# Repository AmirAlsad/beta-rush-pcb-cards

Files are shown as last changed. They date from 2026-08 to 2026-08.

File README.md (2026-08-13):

# Rush Cards — MIT Beta Theta Pi

<p align="center">
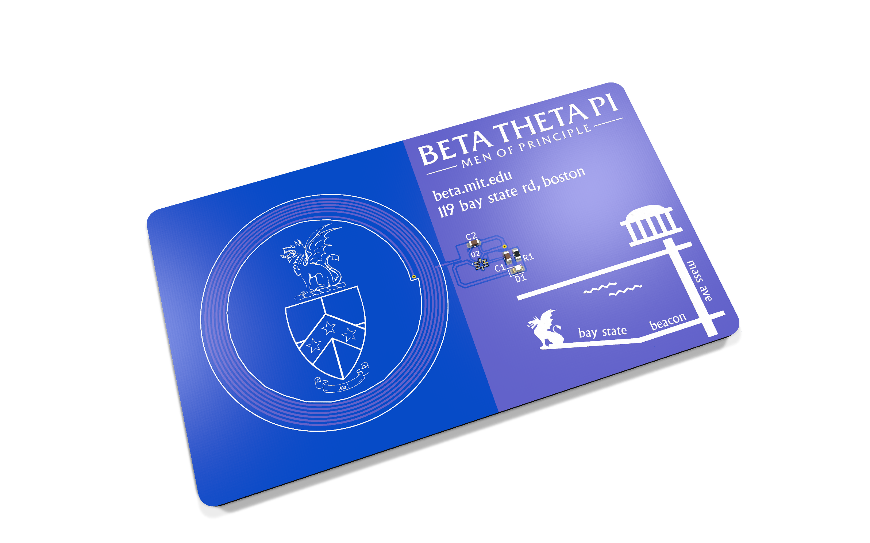
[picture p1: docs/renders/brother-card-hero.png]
The brother card
  
</p>

Two PCB cards designed for **Beta Theta Pi, Beta Eta chapter (MIT)** rush week,
**August 30 – September 6, 2025**. They are circuit boards, not cardstock — the
whole point was that handing someone a PCB is memorable in a way a paper flyer
never is.

**400 cards were made** by JLCPCB — 50 assembled NFC cards and 350 schedule cards — for
**about $400 all-in**. Everything needed to order more is in this repo, including the
exact files JLCPCB received.

> Budget note: the PCB line items were only **$109.80** of that $400. Assembly,
> components, shipping, and import tariffs made up the rest, with freight and tariffs
> taking a large share. **The order-page price is roughly a quarter of what you actually
> pay.** See [`docs/order-history.md`](./docs/order-history.md).

| | |
|---|---|
| **Brother card** | A working NFC tag. A brother taps it to a phone and the phone opens the chapter's rush link. Carried by brothers during rush. **Blue, 1 mm, 50 made, assembled by JLCPCB.** |
| **PNM card** | A silkscreen-only board printing the full week's event schedule, the house address, and the van-pickup number. Handed to PNMs (prospective new members). **Green, 1 mm, 350 made.** |

Designed in **KiCad 9.0.2**. Both boards were fabricated and used.

> **Note for anyone reordering: both cards are 1 mm thick, and every KiCad file here
> says 1.6 mm.** Thickness is an order-page setting that isn't carried in the gerbers,
> so nothing will warn you. Same for the mask colours, which KiCad doesn't store at all.
> [`docs/order-history.md`](./docs/order-history.md) has the complete as-ordered spec.

---

## The boards

### Brother card — front and back

<p align="center">
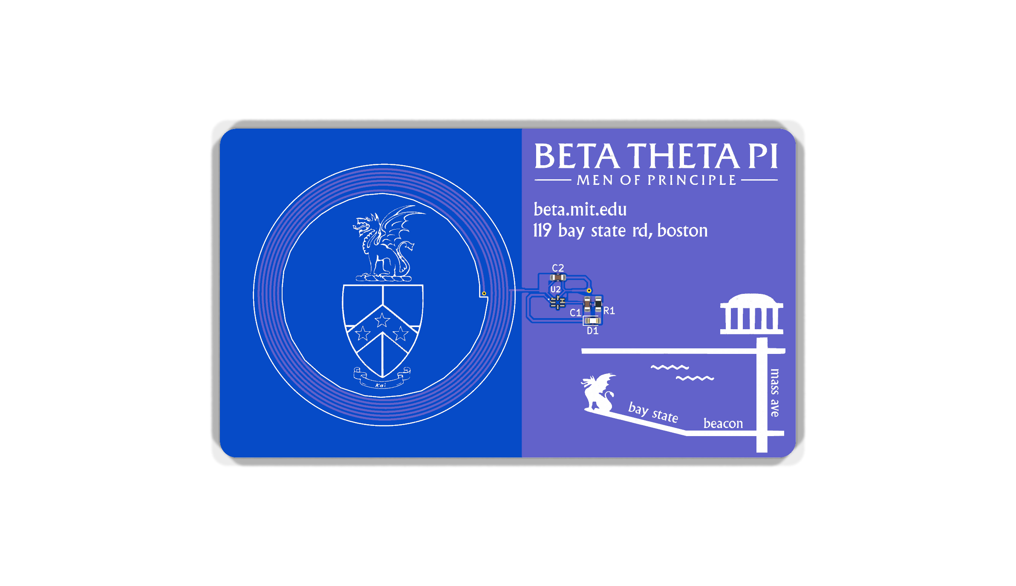
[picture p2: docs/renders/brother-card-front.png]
Brother card front
  
</p>

The left half is a 6-turn spiral NFC antenna in copper, with the Beta crest and
dragon sitting inside the coil. The right half carries the wordmark, the house
address, the tiny NFC circuit (`U2`, `C1`, `C2`, `R1`, `D1`), and a stylized map
of the walk from campus to 119 Bay State Rd — MIT's dome, Mass Ave, the Charles,
Bay State, Beacon.

<p align="center">
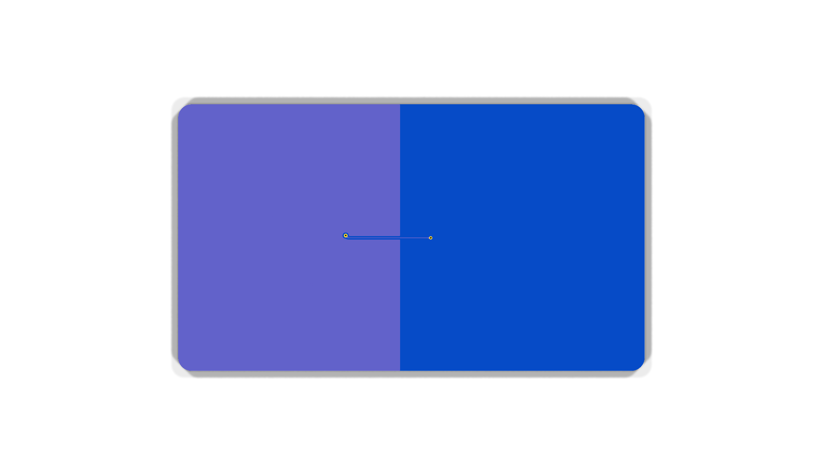
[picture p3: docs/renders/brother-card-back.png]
Brother card back
  
</p>

The back is nearly empty by design: two pads and one short trace that carry the
inner end of the coil back out from under itself. **The two-tone split is not two
solder-mask colours** — it is bare copper zones used as artwork, so a single blue mask
reads as two shades. Never order "two-colour mask" for these.

### PNM card — front and back

<p align="center">
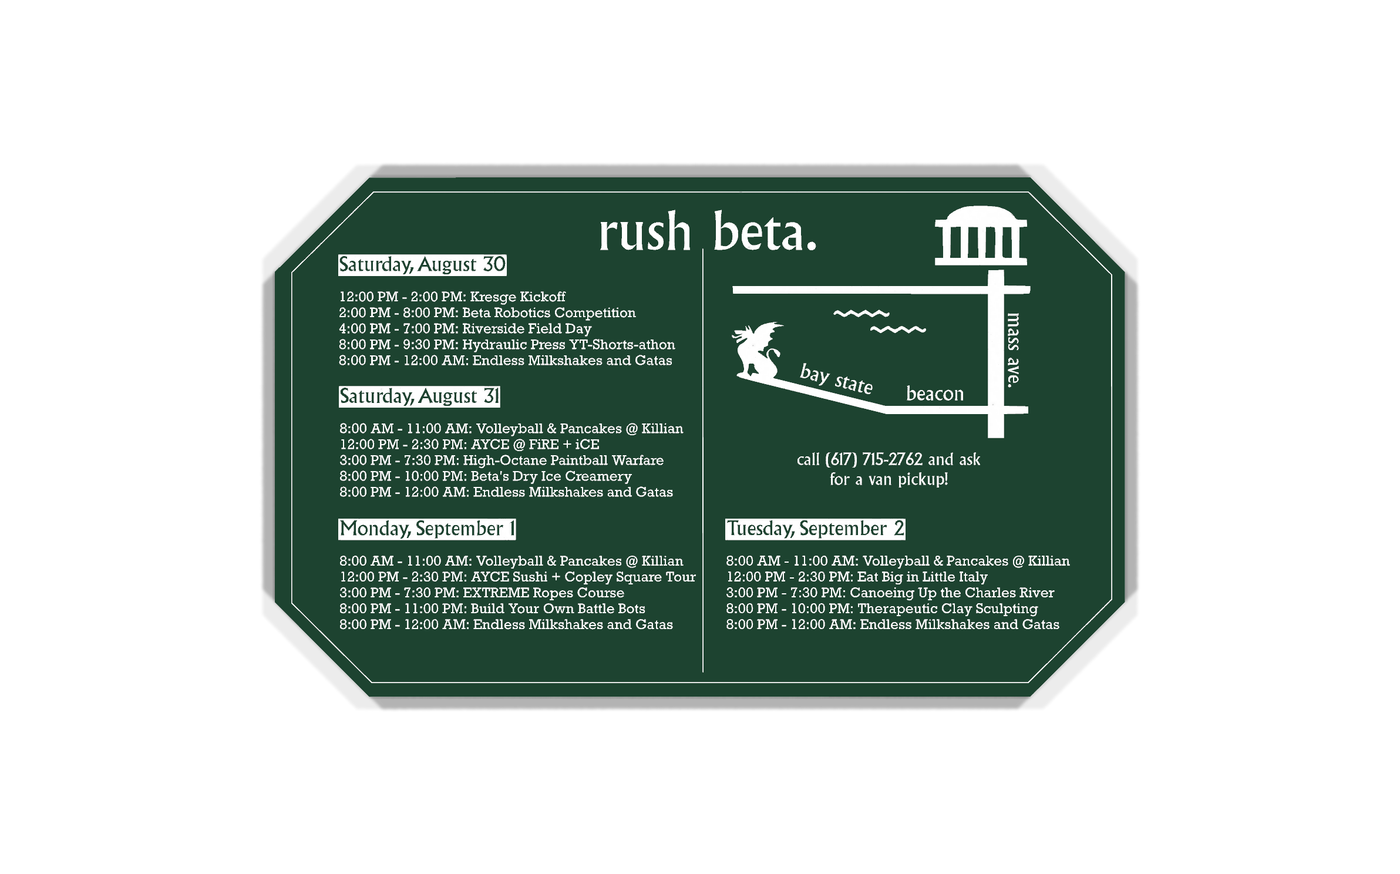
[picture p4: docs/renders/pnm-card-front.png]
PNM card front
  
</p>
<p align="center">
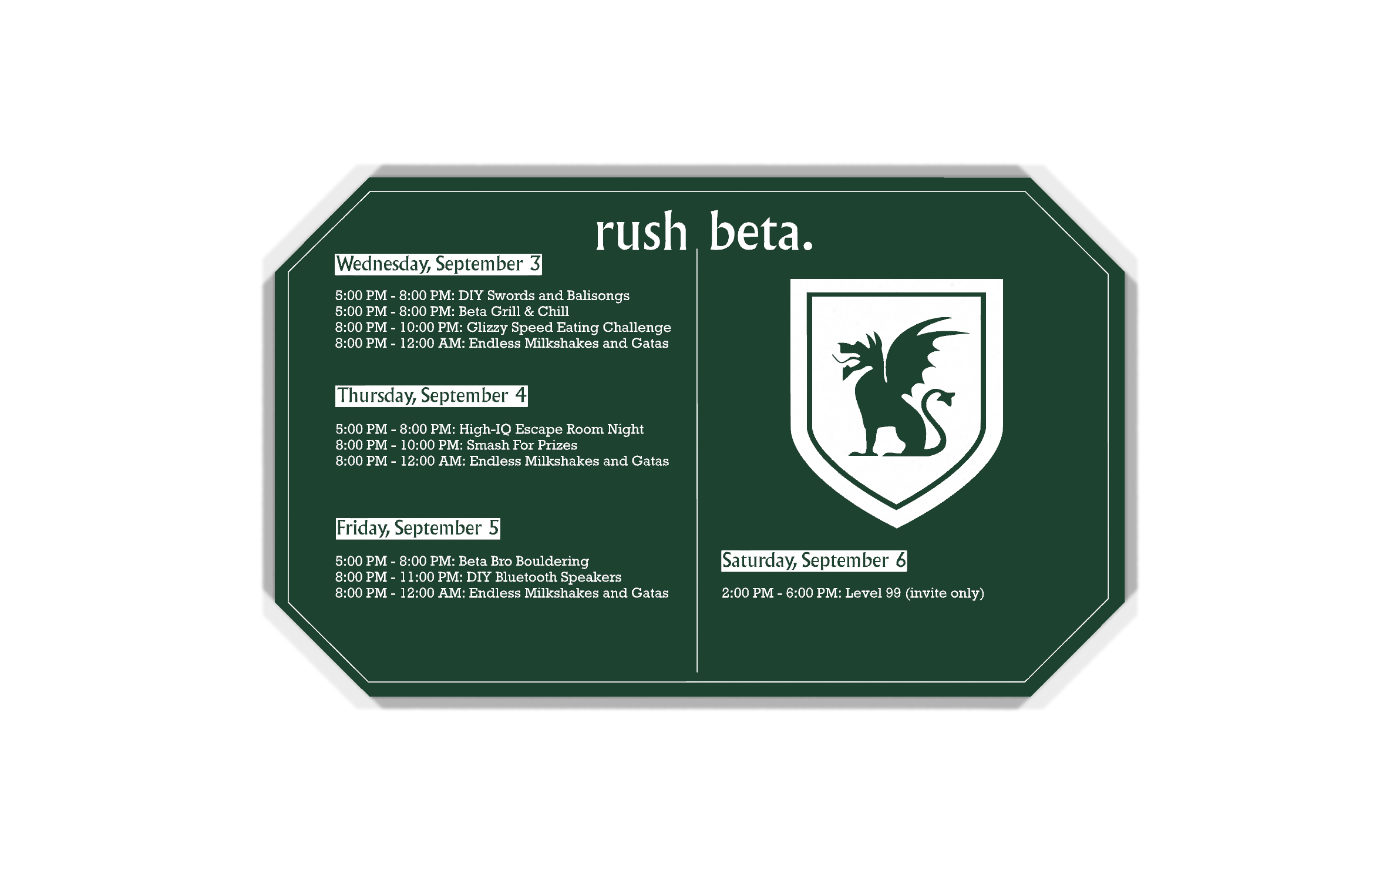
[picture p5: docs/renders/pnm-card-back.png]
PNM card back
  
</p>

Silkscreen only — no components, no nets, nothing to solder. Note the
**octagonal outline**: the corners are clipped on `Edge.Cuts`, which means the
fab has to rout the profile rather than just shear a rectangle.

---

## Repo map

```
.
├── brother-card/        ← the NFC card that was fabricated (v2, 2025-07-30)
├── brother-card-v1/     ← earlier iteration, NEVER fabricated (2025-07-06)
├── pnm-card/            ← the schedule card that was fabricated (2025-07-30)
├── lib/                 ← btp.pretty + btp.kicad_sym  (MUST stay next to the projects)
├── tools/
│   └── render-boards.sh ← regenerates docs/renders/ in the as-ordered mask colours
└── docs/
    ├── order-history.md       ← the 2025 JLCPCB order: spec, prices, parts, gotchas
    ├── reordering.md          ← how to get more cards made
    ├── next-year-checklist.md ← what to change to reuse these for a new rush
    ├── programming-the-tag.md ← how to write the rush link onto a card
    ├── kicad-setup.md         ← opening these files years from now
    ├── nfc-theory.md          ← upstream's full antenna derivation, credited
    ├── OPEN-QUESTIONS.md      ← what still isn't recorded anywhere
    ├── order-history/         ← JLCPCB order screenshots + production records
    ├── renders/               ← generated board renders (+ upstream's Blender model)
    ├── images/                ← upstream's figures, referenced by nfc-theory.md
    ├── antenna-simulations/   ← upstream's LTSpice + MATLAB work
    └── reference/             ← NXP AN11276, ST AN2972, antenna calculators
```

Each card directory holds its own `README.md` with the real detail, the KiCad
source, and a `fab/` folder containing the exact gerbers that were sent out —
**verified byte-identical to the files JLCPCB received.**

**Want to just order more cards?** You don't need KiCad at all. Go straight to
[`docs/reordering.md`](./docs/reordering.md), upload the `fab/…_release/` folders, and
set 1 mm thickness with the right mask colour.

## Opening these in KiCad

```sh
git clone <this repo>
cd RushCards
open brother-card/PCB_Business_Card.kicad_pro   # macOS; or File ▸ Open Project
```

Two things to know before you do, both covered in
[`docs/kicad-setup.md`](./docs/kicad-setup.md):

1. **Don't move `lib/`.** Each project's `fp-lib-table` resolves the artwork
   library as `${KIPRJMOD}/../lib/btp.pretty`. That relative hop is the only
   reason the boards open with their footprints intact — the original design
   depended on a library registered *globally* on one laptop, which would have
   made this repo useless to anyone else. Vendoring it was the single most
   important fix made when archiving.
2. These were built in **KiCad 9.0.2**. A newer KiCad will offer to migrate the
   file format. Let it, but **save to a branch**, and treat `fab/` as the
   authoritative record of what was actually manufactured — see
   [`docs/reordering.md`](./docs/reordering.md).

## Lineage

The brother card is a fork of
**[Raziz1/PCB_Business_Card](https://github.com/Raziz1/PCB_Business_Card)** by
**Rahim Aziz** (forked at commit `fe6c083`). That project's contribution is the
part that is genuinely hard: deriving the antenna geometry from the NFC IC's
50 pF parallel capacitance, simulating it in LTSpice and MATLAB, and confirming
resonance at 13.56 MHz on a real board with a network analyzer. **All of that was
inherited unchanged** and is preserved verbatim in
[`docs/nfc-theory.md`](./docs/nfc-theory.md).

What Beta added: all of the artwork, the Beta symbol/footprint library, a swap to
a smaller NFC IC package with a hand-drawn footprint, and the PNM card (which is
entirely original — it shares nothing with upstream but the toolchain).

## License

Beta's original work here — the artwork, the `btp` library, the board layouts, the
PNM card, and this documentation — is **MIT licensed**. See [`LICENSE`](./LICENSE).

Upstream's inherited material (`docs/nfc-theory.md`, `docs/images/`,
`docs/antenna-simulations/`) is **not** covered: upstream carries no license file, so
it's included with attribution while an explicit grant is sought. The Beta Theta Pi
crest and wordmark are the fraternity's marks and aren't licensed by this repo either.
`LICENSE` spells out each boundary; [`docs/OPEN-QUESTIONS.md`](./docs/OPEN-QUESTIONS.md)
§9 tracks the loose end.

## Reusing these next year

Start at [`docs/next-year-checklist.md`](./docs/next-year-checklist.md). The short
version: the PNM card needs its dates and events retyped every year and nothing else;
the brother card is year-independent, because the rush link is written to the chip
rather than printed on the board.

Three things worth knowing before you start:

- **The 2025 NFC tags were never locked**, so surviving brother cards can simply be
  rewritten — possibly no order needed at all.
- **Program the tags with a permanent redirect you control**, not a destination URL. The
  2025 cards point at a link that has already gone stale after a website change. A stable
  `beta.mit.edu/rush`-style path that redirects means future years change one line on the
  website and never touch hardware again. The chapter is moving to this;
  [`docs/programming-the-tag.md`](./docs/programming-the-tag.md) has the details.
- **The PNM card says "Saturday, August 31"**, but August 31, 2025 was a **Sunday**. The
  typo shipped on the physical cards. It's preserved in the source so the archive matches
  the artifact — fix it when you retype the dates.

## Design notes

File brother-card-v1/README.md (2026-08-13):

# Brother card v1 — earlier iteration, never fabricated

<p align="center">
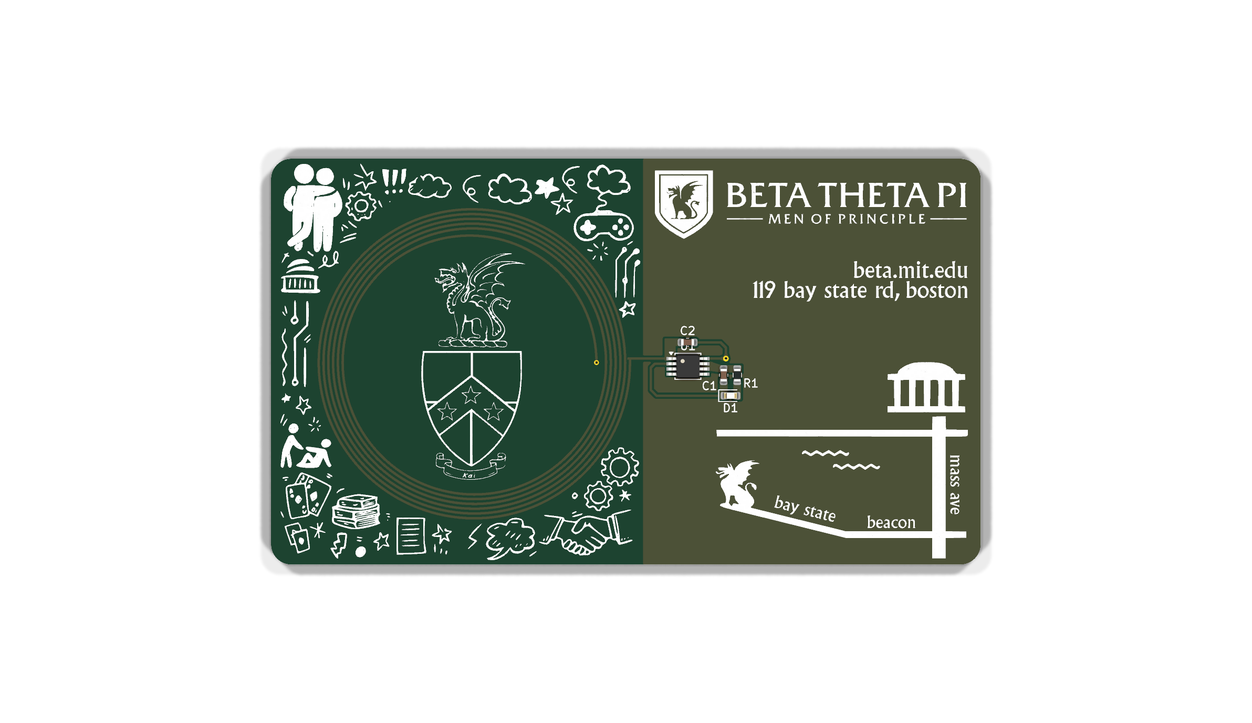
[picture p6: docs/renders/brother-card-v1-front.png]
Brother card v1 front
  
</p>

> **This board was not manufactured.** It is kept because it shows the design one
> step earlier, and because two of its choices are arguably better than the final
> card's. If you're looking for the card that actually existed, go to
> [`../brother-card/`](../brother-card/).

Last saved **2025-07-06**, about three and a half weeks before the final version.

## What changed between v1 and v2

| | v1 (this folder) | v2 (fabricated) |
|---|---|---|
| NFC IC | `NT3H1101W0FTTJ` — **TSSOP-8, 0.65 mm pitch** | `NT3H2111W0FHKH` — XQFN8, 1.6 × 1.6 mm, 0.5 mm pitch |
| IC footprint | `Package_SO:TSSOP-8_3x3mm_P0.65mm` (stock KiCad) | `btp:nfc-chip` (hand-drawn) |
| Left-half art | Doodle border (162 polygons) ringing the crest | Doodles removed; crest and coil given the space |
| Wordmark | `btp:btp-text-footprint-lg` — includes the shield | Plain `BETA THETA PI / MEN OF PRINCIPLE`, no shield |
| Coil | Smaller, set inside the doodle frame | Larger, fills the half |
| DRC | 21 violations, **1 unconnected item** | 19 violations, 0 unconnected |
| Fab output | none | `fab/2025-07-30_release/` |

The doodle border is the most visually distinctive thing this repo contains and it
did not survive to production — gamepads, gears, a card hand, books, a handshake,
the MIT dome, two figures. It's still in the vendored library as `btp:doodles`
(162 polygons) if a future year wants it back.

## Two reasons to look here before starting a v3

1. **The doodle art.** Reusing it is a copy-paste of `btp:doodles`, not a redraw. This is
   the main reason to keep this folder.
2. **TSSOP-8, but only if you're hand-assembling.** v2's XQFN8 is a 1.6 mm square with
   0.5 mm pitch and no exposed pad — genuinely hard to place by hand. v1's TSSOP-8 has
   0.65 mm pitch and gull-wing leads you can touch with an iron. Both are the same NTAG
   I²C family and pin-compatible for this circuit's purposes (`LA`/`LB` to the coil,
   `VCC` to the LED, I²C unused).

   **This mattered less than it looks.** The 2025 cards were **machine-assembled by
   JLCPCB** ([`../docs/order-history.md`](../docs/order-history.md)), so the fine pitch
   was never a problem in practice — a pick-and-place doesn't care. Revisit the package
   only if a future year genuinely intends to hand-solder a batch.

## Caveats

- **It has 1 unconnected item.** This is an unfinished board. Don't send it to a fab
  without finishing the netlist.
- Its NFC symbol comes from `NT3H1101W0FTTJ:NT3H1101W0FTTJ`, a library that lived on
  upstream's Windows machine (`C:/Users/rahim/Downloads/...`) and does not exist
  anywhere in this repo. The symbol still **opens fine** because KiCad caches symbol
  definitions inside the `.kicad_sch` — but you can't update it from library, and
  Eeschema will flag the library as missing. Same for the bare `COIL_GENERATOR`
  footprint link.
- The antenna and matching network are identical in principle to v2's; see
  [`../brother-card/README.md`](../brother-card/README.md) and
  [`../docs/nfc-theory.md`](../docs/nfc-theory.md).
- `fab/2025-07-06_export/` contains a gerber export from this iteration **plus a
  `BOM.csv` inherited from upstream that still lists upstream's parts**
  (`NT3H1101W0FTTJ` in `TSSOP-8`, `REF**` for the coil). It documents where the
  design was mid-stream. It is not a release.

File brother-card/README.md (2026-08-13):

# Brother card (v2) — the NFC card that was fabricated

<p align="center">
  Brother card front
</p>

A brother taps this card to a phone; the phone opens the chapter's rush link. No
battery, no app on the brother's side — the card is a passive NFC tag that
harvests power from the reader's field.

**This is the version that was manufactured and used during rush week 2025.** The
earlier iteration in [`../brother-card-v1/`](../brother-card-v1/) was never built.

| | |
|---|---|
| Source of record | `PCB_Business_Card.kicad_pcb`, last saved **2025-07-30** |
| Designed in | KiCad **9.0.2** |
| Outline | **88.9 × 50.8 mm** — exactly 3.5 × 2 in, a standard business-card footprint |
| Stackup in the file | 2 layer FR4, 1.6 mm, 35 µm (1 oz) copper |
| **As actually ordered** | **1 mm thick, blue mask, white silkscreen** — 50 pcs, assembled by JLCPCB |
| Fab package | [`fab/2025-07-30_release/`](./fab/2025-07-30_release/) — byte-identical to what JLCPCB received |
| Order record | [`../docs/order-history.md`](../docs/order-history.md) |

> **The file says 1.6 mm; the cards are 1 mm.** Thickness is an order-page setting that
> isn't stored in the gerbers, so nothing reconciles this automatically. Likewise the mask
> is **blue**, which KiCad doesn't record either — the renders on this page were generated
> with the as-ordered colour injected ([`../tools/render-boards.sh`](../tools/render-boards.sh)).

## How it works

A phone's NFC reader radiates a 13.56 MHz field. The spiral coil on the left half
of the card (`ANT1`) is an inductor tuned, together with the IC's internal 50 pF
and the tuning cap `C2`, to resonate at that frequency. At resonance the coil
couples strongly to the phone, and the induced current does two jobs: it powers
the tag IC, and it carries the load-modulated reply back to the phone.

The IC holds an **NDEF record containing the rush URL**. The phone reads it and
offers to open the link. Nothing is stored on the board itself — see
[`../docs/programming-the-tag.md`](../docs/programming-the-tag.md) for how the URL
gets written, which is what you'd redo for a new year.

`D1` is not part of the NFC path at all. It's an energy-harvesting indicator: when
the field is strong enough, the IC's `VCC` output drives the LED through `R1`, so
the card visibly lights up when it's being read. It's a party trick, and a genuinely
useful bring-up probe — if the LED lights, the coil is coupling.

## Bill of materials

Schematic values on the left, the parts **actually fitted** by JLCPCB on the right.

| Ref | Schematic | Part ordered | JLCPCB code | Purpose |
|---|---|---|---|---|
| `U2` | `NT3H2111W0FHKH` | **NT3H2111W0FHKH** — XQFN8, 1.6 × 1.6 mm, 0.5 mm pitch | `C710403` | NXP NTAG I²C *plus* — the tag IC |
| `ANT1` | `COIL_GENERATOR` | *copper on the board, not a placed part* | — | 6-turn spiral antenna |
| `C1` | `220n` | **CL10B224KA8NNNC** — 220 nF 0603 X7R | `C21120` | Holds the harvested rail up during RF communication |
| `C2` | `2p` | **0603CG2R0C500NT** — **2.0 pF** 0603 C0G 50 V | `C1650` | Antenna tuning capacitor |
| `R1` | `65` | **0603WAF649JT5E** — **64.9 Ω** 1% 0603 | `C23224` | LED current limit: (3.3 V − 2 V) / 20 mA |
| `D1` | `RED` | **LTST-C190KRKT** — red 0603 | `C94869` | Energy-harvest indicator |

`U2`'s `SDA`, `SCL`, and `FD` pins are deliberately left unconnected — the I²C side
of the NTAG is unused here. The card is a pure NFC-Forum Type 2 tag.

> **`C2` is 2.0 pF — this used to be the one uncertain number, and it is now settled.**
> Upstream's write-up quotes **3.9 pF** as their measured optimum and lists **1.5 pF** in
> their parts list, so for a while three values were in play. JLCPCB's parts list for this
> order resolves it: the Beta cards were built with **2.0 pF**, matching the schematic's
> `2p`, and they worked. Upstream's figures were for *their* board geometry.
>
> Reorder with 2.0 pF. If you ever want to chase more read range you can sweep it on
> hardware — [`../docs/nfc-theory.md`](../docs/nfc-theory.md) walks the measurement — but
> don't change it speculatively. Upstream showed the card still reads even with a badly
> mistuned 15 pF cap, just at shorter range, so this parameter trades range rather than
> breaking function.

## The antenna

Inherited unchanged from upstream. Extracted from `lib/btp.pretty/COIL_GENERATOR.kicad_mod`:

| Parameter | Value |
|---|---|
| Turns | **6** |
| Outer / inner diameter | **39.6 mm** / 31.2 mm |
| Track width / gap | **0.3 mm** / 0.3 mm (0.6 mm pitch) |
| Layer | `F.Cu`, with the inner end crossing over on `B.Cu` |
| Crossover | 0.3 mm drill PTH |
| Calculated inductance | **2.576 µH** (upstream) |
| Modelled parasitics | R≈1.17 Ω, C≈2 pF (upstream) |
| Simulated resonance, untuned | 13.75 MHz (upstream) |
| Measured resonance, 3.9 pF tuning cap | **13.555 MHz** (upstream, network analyzer) |

The coil is drawn as **graphic arcs inside a footprint**, not as routed track. That
is why the inner end has to leave through a through-hole pad and return on the back
side, and it's why DRC complains (below). The derivation of these numbers — working
backwards from the IC's 50 pF to a target inductance, then to a geometry — is
upstream's work and is preserved in full in
[`../docs/nfc-theory.md`](../docs/nfc-theory.md).

## Artwork

The visual design is the part that is original to Beta. Three things worth knowing
if you edit it:

- **The two-tone card is copper, not two mask colours.** The card was ordered in
  **blue**, and the lighter blue-violet half is bare copper under that single mask.
  Ordering "two-colour solder mask" would be a waste of money — one colour is all this
  needs.
- **Artwork is polygons in footprints**, produced by KiCad's *Bitmap to Component*
  converter from PNG art, then placed like parts. `btp:btp-dragon-footprint` (crest
  + dragon, 35 polygons), `btp:map` (the Back Bay map, 4 polygons), and the
  `BETA THETA PI / MEN OF PRINCIPLE` wordmark (27 polygons).
- **Two footprints on this board have no working library link**, because they were
  placed before being saved to a library:
  - the wordmark, whose stale link is the bare name `LOGO`. Its geometric twin
    **is** in the repo as `btp:btp-text-only-lg` (also 27 polygons) — relinking is
    optional cosmetic cleanup.
  - a single-pad unnamed footprint that anchors the coil crossover.

  Both are fully stored inside the `.kicad_pcb`, so they render, plot, and fabricate
  correctly. They just can't be *updated from library*. **Don't delete them
  casually.**

## Fab packages

| Folder | What it is |
|---|---|
| [`fab/2025-07-30_release/`](./fab/2025-07-30_release/) | **The authoritative set.** 9 gerbers + 2 drill files + placement/BOM CSVs, plotted from KiCad 9.0.2. This is the geometry that became physical cards. |
| [`fab/2025-07-30_full-export/`](./fab/2025-07-30_full-export/) | An earlier export the same day, with `F.Fab`, courtyard, and margin layers included. Useful for reading, **not** for ordering — documentation layers are not manufacturing data. |
| [`fab/2025-07-30_placement/`](./fab/2025-07-30_placement/) | Placement CSVs plus a Numbers spreadsheet used while reconciling the assembly. |
| [`fab/jlcpcb-assembly/`](./fab/jlcpcb-assembly/) | The JLCPCB-format **BOM and CPL** used to order assembly. Upload these with the release gerbers to get populated boards. |

**The release set has been byte-compared against the files JLCPCB actually received**
and is identical, so reordering from it reproduces the 2025 cards exactly. The gerbers
report `88.95 × 50.85 mm` (outline centreline plus line width) and were plotted with a
`0.1524 mm` minimum feature. Their timestamps read `18:41 UTC+03:00` — the laptop's clock
was on a +03:00 timezone, so that's `11:41` Boston time, not evening.

**Reorder from `fab/2025-07-30_release/`, not from a fresh plot.** Regenerating
gerbers in a newer KiCad produces subtly different zone fills and teardrop
geometry for the same source, and this artwork leans on zone fills.
[`../docs/reordering.md`](../docs/reordering.md) explains the tradeoff.

## Known DRC findings — all expected

KiCad 10 reports **19 violations, 0 unconnected items, 0 schematic-parity errors**.
Every violation is an artifact of the artwork technique, and the cards work:

| Finding | Why it's benign |
|---|---|
| 3 × `shorting_items`, 2 × `clearance`, 1 × `solder_mask_bridge` | The coil is netless graphic arcs that intentionally touch `ANT1`'s pads. DRC sees "no net" copper contacting `/NFC-A` and `/NFC-B` and calls it a short. It *is* the connection. |
| 2 × `isolated_copper` | The decorative copper zones have no net by design — that's the two-tone effect. |
| 5 × `text_thickness` | Silkscreen strokes thinner than the 0.15 mm rule. The fab rendered them fine. |
| 1 × `track_dangling` | A 3 × 10⁻⁵ mm stub — a rounding artifact, not a real track. |
| 1 × `lib_footprint_mismatch` | `btp-dragon-footprint` was tweaked in place after placement, so the board copy differs from `lib/`. **The board is authoritative.** |
| 4 × `lib_footprint_issues` | Stock KiCad libraries (`Capacitor_SMD`, `Resistor_SMD`, `LED_SMD`) not registered in a headless CLI run. They resolve in the GUI. **`btp` resolves correctly** — that was the point of vendoring it. |

Do not "fix" the shorting/clearance findings by rerouting the coil. If you need a
clean DRC, add exclusions.

## Assembly

**The 50 cards were machine-assembled by JLCPCB**, top side, high-temp paste — not
hand-soldered. Which is fortunate, because the IC is the awkward part: **XQFN8,
1.6 × 1.6 mm, 0.5 mm pitch, 0.71 × 0.22 mm pads, no exposed thermal pad.**

Two consequences of ordering assembly, both covered in
[`../docs/order-history.md`](../docs/order-history.md):

- **JLCPCB adds two 10 mm edge rails** to carry fiducials and its SMT tracking QR code,
  which is why the order dimension reads 88.9 × **70.8** mm rather than 88.9 × 50.8 mm.
  The rails are V-scored off, and the QR marks go with them, so the card faces stay clean.
- **Depaneling was not paid for in 2025**, so the cards arrived with rails attached and
  someone snapped all 50 off by hand. Tick that box next time.

If you ever do assemble by hand, [`../brother-card-v1/`](../brother-card-v1/) used a
pin-compatible **TSSOP-8** version of the same NTAG family — 0.65 mm pitch and gull-wing
leads — which is far friendlier to an iron.

`D1` is the bring-up test: hold the card to a phone with NFC on, and the LED should
light. If it lights but the phone shows nothing, the coil is fine and the problem is
the tag's contents — go to
[`../docs/programming-the-tag.md`](../docs/programming-the-tag.md).

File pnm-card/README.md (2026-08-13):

# PNM card — the rush schedule board

<p align="center">
  PNM card front
</p>
<p align="center">
  PNM card back
</p>

Handed to PNMs (prospective new members) during rush. It's a PCB purely as a
gimmick — there is **no circuit here at all**: no components, no nets, no copper
routing. The schematic is an empty sheet. Everything you see is silkscreen on a
bare two-layer board.

That makes this the easy card to reuse: nothing electrical can break, and the only
work each year is retyping the schedule.

| | |
|---|---|
| Source of record | `PNM_Rush_Card.kicad_pcb`, last saved **2025-07-30** |
| Designed in | KiCad **9.0.2** |
| Outline | **89.98 × 54.97 mm**, octagonal (clipped corners) |
| Stackup in the file | 2 layer FR4, 1.6 mm |
| **As actually ordered** | **1 mm thick, green mask, white silkscreen** — **350 pcs, $86.10** |
| Layers used | `F.SilkS` (28 items), `B.SilkS` (22), `Edge.Cuts` (8), one placeholder item each on `F.Cu` / `B.Cu` |
| Fab package | [`fab/2025-07-30_release/`](./fab/2025-07-30_release/) — byte-identical to what JLCPCB received |
| Order record | [`../docs/order-history.md`](../docs/order-history.md) |

> **The file says 1.6 mm; the cards are 1 mm.** Thickness is an order-page setting that
> isn't carried in the gerbers, so nothing reconciles it automatically. Set 1 mm explicitly
> on a reorder or you'll get noticeably chunkier cards.

## The outline is the one thing that costs money

The corners are **chamfered** — `Edge.Cuts` is an octagon, not a rectangle. A
rectangular card can be sheared or V-scored cheaply; this profile has to be
**routed**. When quoting, make sure the vendor is pricing a routed outline and
isn't silently substituting a rectangle. This is the single most likely way a
reorder comes back looking wrong.

JLCPCB got this right in 2025: its production file set for this card contains **no V-cut
layer at all** (and no drill file, since there are no holes), confirming the profile was
routed as intended. The brother card's set, by contrast, does have a V-cut layer — for the
assembly edge rails.

## What's printed on it

**Front** — `rush beta.`, the Back Bay map (MIT dome, Mass Ave, Charles, Bay
State, Beacon), `call (617) 715-2762 and ask for a van pickup!`, and the first
four days:

| Day | Events |
|---|---|
| **Saturday, August 30** | Kresge Kickoff · Beta Robotics Competition · Riverside Field Day · Hydraulic Press YT-Shorts-athon · Endless Milkshakes and Gatas |
| **"Saturday, August 31"** ⚠️ | Volleyball & Pancakes @ Killian · AYCE @ FiRE + iCE · High-Octane Paintball Warfare · Beta's Dry Ice Creamery · Endless Milkshakes and Gatas |
| **Monday, September 1** | Volleyball & Pancakes @ Killian · AYCE Sushi + Copley Square Tour · EXTREME Ropes Course · Build Your Own Battle Bots · Endless Milkshakes and Gatas |
| **Tuesday, September 2** | Volleyball & Pancakes @ Killian · Eat Big in Little Italy · Canoeing Up the Charles River · Therapeutic Clay Sculpting · Endless Milkshakes and Gatas |

**Back** — `rush beta.`, the crest, and the rest of the week:

| Day | Events |
|---|---|
| **Wednesday, September 3** | DIY Swords and Balisongs · Beta Grill & Chill · Glizzy Speed Eating Challenge · Endless Milkshakes and Gatas |
| **Thursday, September 4** | High-IQ Escape Room Night · Smash For Prizes · Endless Milkshakes and Gatas |
| **Friday, September 5** | Beta Bro Bouldering · DIY Bluetooth Speakers · Endless Milkshakes and Gatas |
| **Saturday, September 6** | Level 99 (invite only) |

> ⚠️ **A typo shipped on the physical cards.** The second block reads
> **"Saturday, August 31"**, but August 31, 2025 was a **Sunday**. Every other day
> label is correct. It is left uncorrected in the source so this archive matches the
> object that was actually handed out — fix it when you retype the dates for a new
> year.

## Artwork

Same technique as the brother card: art is polygons inside footprints, generated
with KiCad's *Bitmap to Component* converter. This board places `btp:map` (from the
vendored [`../lib/`](../lib/)) and one wordmark/crest footprint whose library link
is the stale bare name `LOGO` — it lives inside the `.kicad_pcb` and plots
correctly, but can't be *updated from library*. Don't delete it casually.

Event text is ordinary KiCad text objects with embedded `\n` line breaks, which is
what makes this card straightforward to retype — see
[`../docs/next-year-checklist.md`](../docs/next-year-checklist.md).

## Known DRC findings — all expected

KiCad 10 reports **21 violations, all `text_thickness`**, and nothing else: no
clearance errors, no unconnected items, no parity errors. The warnings say the
silkscreen stroke width is below the 0.15 mm design rule. The fab printed them
legibly anyway, as the renders show.

If you shrink the text further to fit more events, that warning is the thing to
actually pay attention to — at some point thin silkscreen stops resolving and
becomes unreadable. Keep an eye on the smallest strokes and ask the vendor for
their real minimum line width.

## Fab package

[`fab/2025-07-30_release/`](./fab/2025-07-30_release/) holds the gerbers that were
sent out: `F.Cu`, `B.Cu`, both silkscreens, both masks, both pastes, `Edge.Cuts`,
and two drill files (both empty — there is nothing to drill). Plotted from
KiCad 9.0.2; the job file reports `90.03 × 55.02 mm`.

**These have been byte-compared against the files JLCPCB actually received** and are
identical, so reordering from this folder reproduces the 2025 cards exactly.

One aesthetic note: the order specified **Mark on PCB: Order Number**, and unlike the
brother card this one has no edge rails for JLCPCB to hide that marking on. **There is
probably a small JLCPCB order number printed somewhere on a face of the delivered cards.**
If that matters, pick "Remove order number" or specify a location next time.

The silkscreen gerbers are large (1.1 MB front, 658 KB back) because all that text
and artwork is flattened to polygons. That's normal, not corruption.

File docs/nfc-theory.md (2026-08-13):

# Upstream design document — NFC PCB business card

> **Attribution.** Everything below this banner is the original `README.md` from
> **[Raziz1/PCB_Business_Card](https://github.com/Raziz1/PCB_Business_Card)** by
> **Rahim Aziz**, reproduced verbatim (commit `fe6c083`) because it is the
> engineering derivation behind the brother card's antenna and matching network.
> Both Beta cards are forks of that project. Only the relative image paths below
> were rewritten to match this repo's layout — no wording, math, or figure was
> altered.
>
> The upstream repository carries **no explicit license file**. See
> [`OPEN-QUESTIONS.md`](./OPEN-QUESTIONS.md) — asking Rahim for a license grant
> is a loose end worth closing.
>
> **What Beta changed** relative to this document is written up in
> [`../brother-card/README.md`](../brother-card/README.md). The antenna geometry,
> tuning capacitor, LED bias resistor, and all of the theory below were
> *inherited unchanged*.

---

# PCB Business Card 💳
The following project is a PCB designed as a business card. This card contains an integrated NFC tag that allows you to share your contact information wirelessly.

<p align="center">
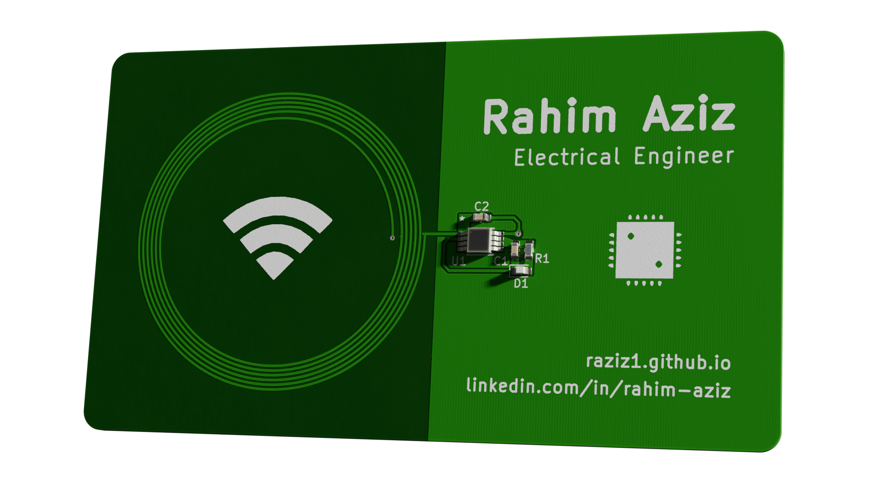
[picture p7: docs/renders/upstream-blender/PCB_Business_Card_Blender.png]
PCB Business Card PCB Business Card Render
    
</p>
<p align="center"><i>Blender Render</i></p>

## NFC Principle 🧲
<b>[NFC (Near Field Communication)](https://www.spiceworks.com/tech/networking/articles/what-is-near-field-communication/)</b> is a group of communication protocols that allows for low speed wireless communication between two electronic devices. 
* NFC communication occurs when both electronic devices are within a distance of 4cm or less. 
* NFC operates at 13.56 MHz on ISO/IEC 18000-3 air interface and at rates ranging from 106 kbit/s to 424 kbit/s.
* The transfer of data in NFC is bi-directional.
* NFC has a setup time of 0.1s. For reference, Bluetooth requires a setup time of 6s.
* NFC utilizes the phenomenon of inductive coupling between two electromagnetic coils.

<p align="center">
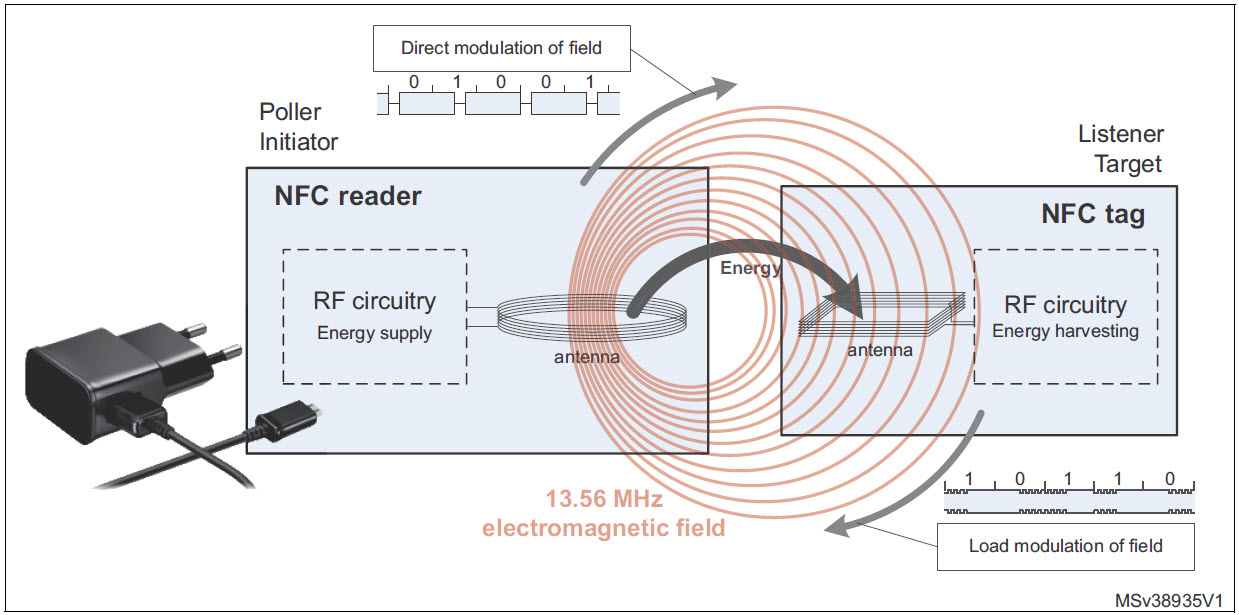
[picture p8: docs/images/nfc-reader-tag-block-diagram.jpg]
NFC Principle
    
</p>

## NFC IC 📶
THe NFC IC being used in this project is the [NT3H1101W0FTTJ](https://www.digikey.ca/en/products/detail/nxp-usa-inc/NT3H1101W0FTTJ/5347877).
* This chip is an NFC chip designed by NXP. It features I2C communication, energy harvesting, and field detection features. 
* It features 64 bytes of SRAM and 1kB of EEPROM memory. We can use the onboard memory to stored a personal website link for the user device to retrieve when communicating with the IC.
* Lastly with this chip, we can utilize the induced current to power the chip (i.e., energy harvesting).
* We can program the IC through the [NFC TagWriter by NXP](https://play.google.com/store/apps/details?id=com.nxp.nfc.tagwriter&hl=en_GB) app.

<p align="center">
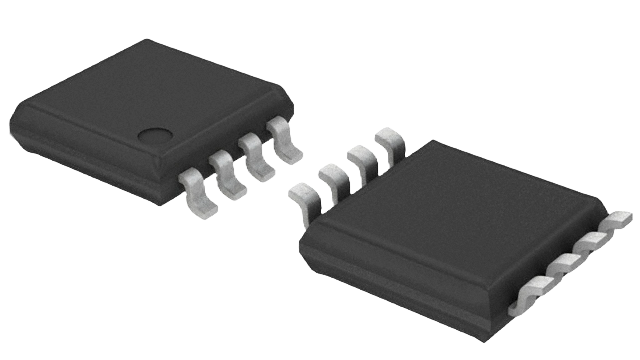
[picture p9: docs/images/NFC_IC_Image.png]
NFC IC NFC IC
    
</p>

## NFC Equivalent Circuit
The internet has a plethora of resources for antenna design. The two sources I will be referring to for this design are:
* [AN11276 - NXP Community](https://community.nxp.com/pwmxy87654/attachments/pwmxy87654/nfc/6155/1/AN11276.pdf)
* [AN2972 Application note How to design an antenna for dynamic NFC tags](https://www.st.com/resource/en/application_note/an2972-how-to-design-an-antenna-for-dynamic-nfc-tags-stmicroelectronics.pdf)

The figure below shows the equivalent electrical circuits of the dynamic NFC tag and its antenna.

<p align="center">
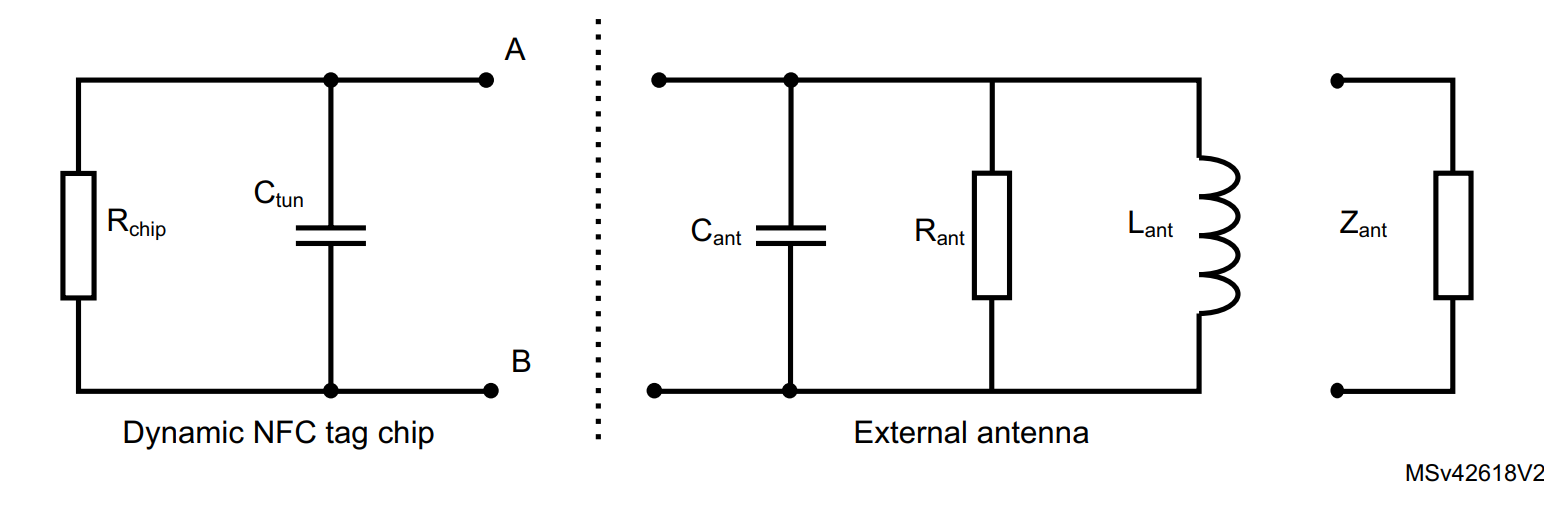
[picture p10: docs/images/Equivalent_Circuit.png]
NFC Equivalent Circuit
    
</p>

The above circuit can be simplified into an equivalent RLC circuit.

<p align="center">
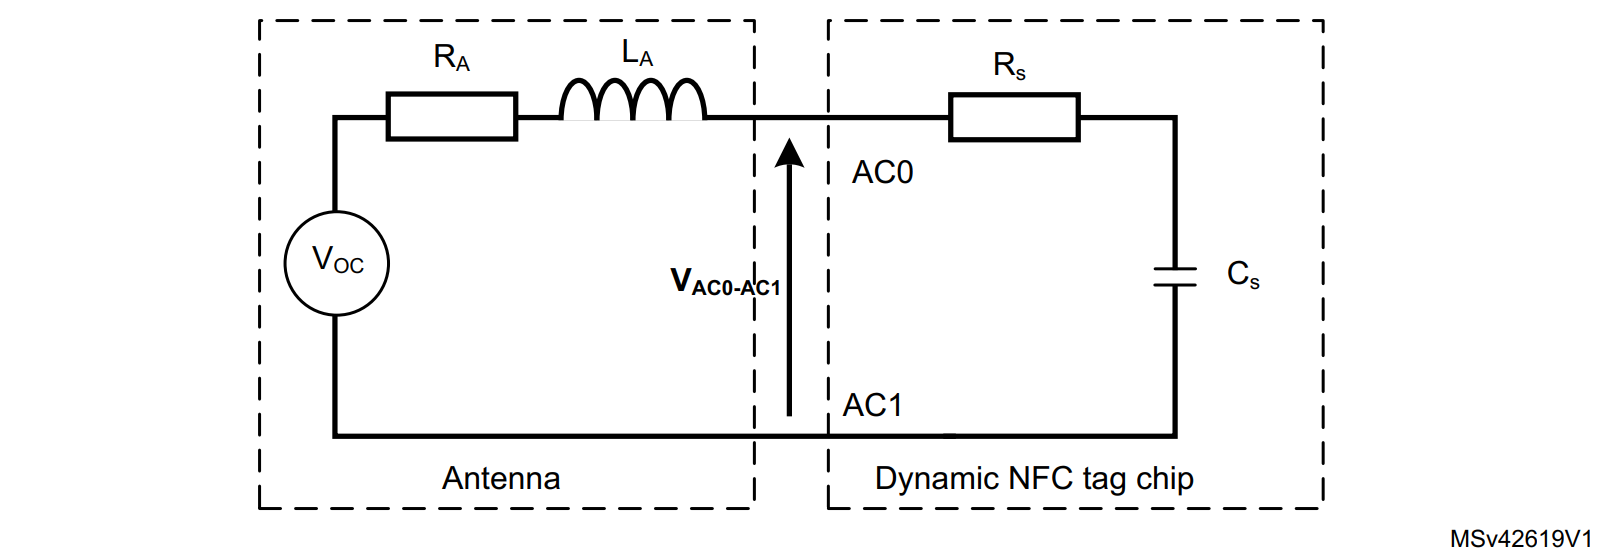
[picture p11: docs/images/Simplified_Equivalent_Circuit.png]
NFC RLC Circuit
    
</p>

### Resonance Frequency
Based on the simplified RLC circuit we can determine the resonant frequency. 
* Resonance frequency is the frequency (in hertz) in which a signal or power level can be carried, or couple from one device to another with no power or signal loss "ideally".
* $f_R=\frac{1}{2\cdot \pi \cdot \sqrt{L_{pc}\cdot C_{pl}}}$
    * $C_{pl}=C_{tun}+C_{ant}$

We know that for an NFC tag, the desired frequency is 13.56 MHz. We also know that the IC's parallel capacitance is 50 pF (from the datasheet). <i>Ignore the parasitic capacitance of the antenna for now; we will come back to that</i>. Based on this information, we can work backwards to determine the required inductance of the antenna.

$f_R=\frac{1}{2\cdot \pi \cdot \sqrt{L_{pc}\cdot C_{pl}}}$

$L_{pc}=\frac{1}{C_{pl}\left(2\pi f_R\right)^2}$

$L_{pc}=\frac{1}{5\cdot 10^{-11}\left(2\pi \cdot 13560000\right)^2} = 0.00000275518$

$L_{pc}=0.00000275518\:H=\:2.75518\:uH$

## Antenna Design 📡
We can now design an NFC antenna based on the desired inductance calculated above. To design the antenna I referred to various resources to confirm my calculations. 

### NXP Spiral Antenna Calculation
The [AN11276 NTAG Antenna Design Guide](https://community.nxp.com/pwmxy87654/attachments/pwmxy87654/nfc/6155/1/AN11276.pdf) provides the following information to design an antenna. 

<p align="center">
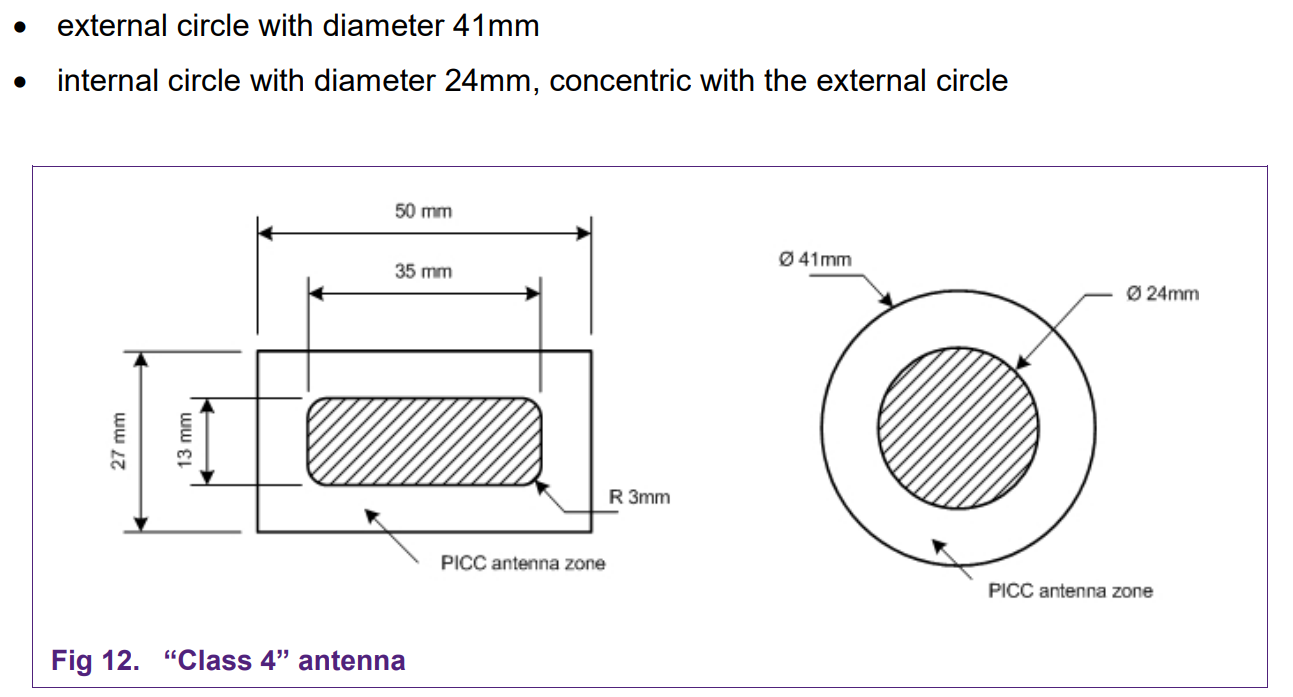
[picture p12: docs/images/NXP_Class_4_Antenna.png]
    
</p>
<p align="center"><i>NXP Class 4 Antenna Design Recommendation</i></p>

<p align="center">
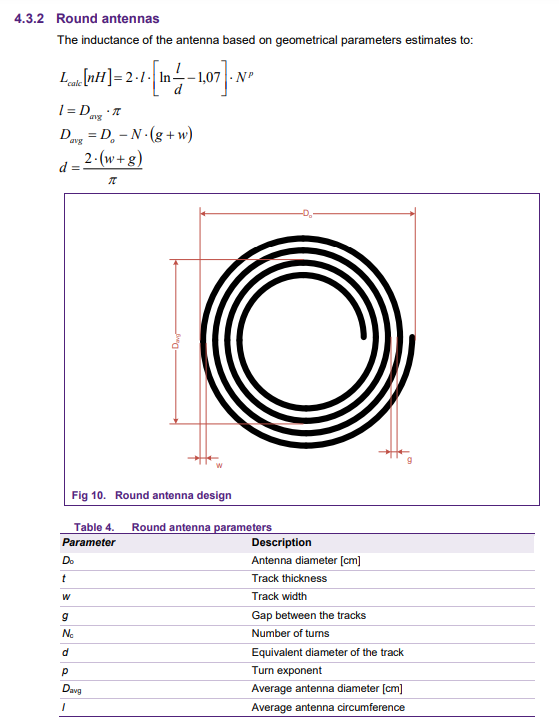
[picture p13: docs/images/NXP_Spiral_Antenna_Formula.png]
NXP Spiral Formula
    
</p>
<p align="center"><i>NXP Round Antennas Formula</i></p>

I utilized the [Antenna_Shape_Calculator](./reference/Antenna_Shape_Calculator.xlsx) excel document to calculate the geometric parameters. They were as follows:
* $D_0 = 41mm$
* $t = 35um$
* $w = 300um$
* $g = 300um$
* $Nant = 6\:turns$
* $L_{calc} = 2.754uH$

### STM Spiral Antenna Calculation
The [AN2972 Application note](https://www.st.com/resource/en/application_note/an2972-how-to-design-an-antenna-for-dynamic-nfc-tags-stmicroelectronics.pdf) provides the following information to design an antenna. 

<p align="center">
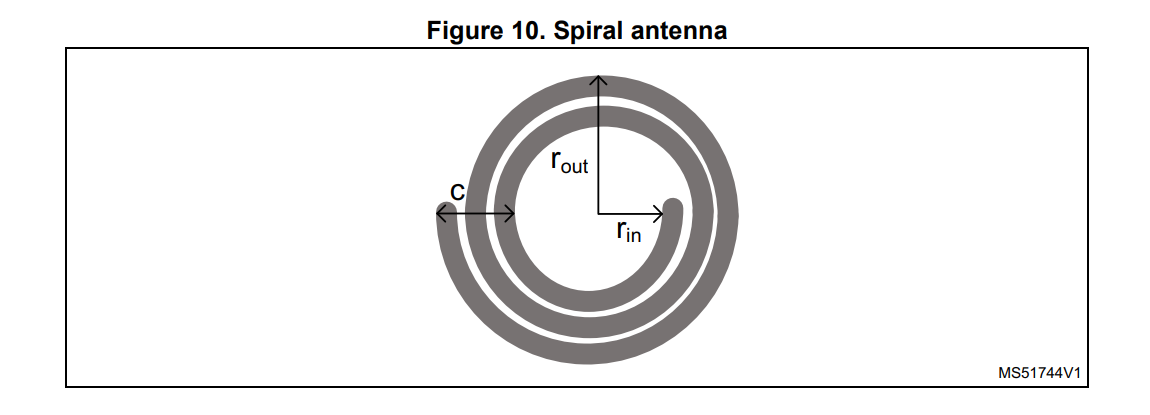
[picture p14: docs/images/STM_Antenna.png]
    
</p>
<p align="center"><i>STM Spiral Antenna Design</i></p>

<p align="center">
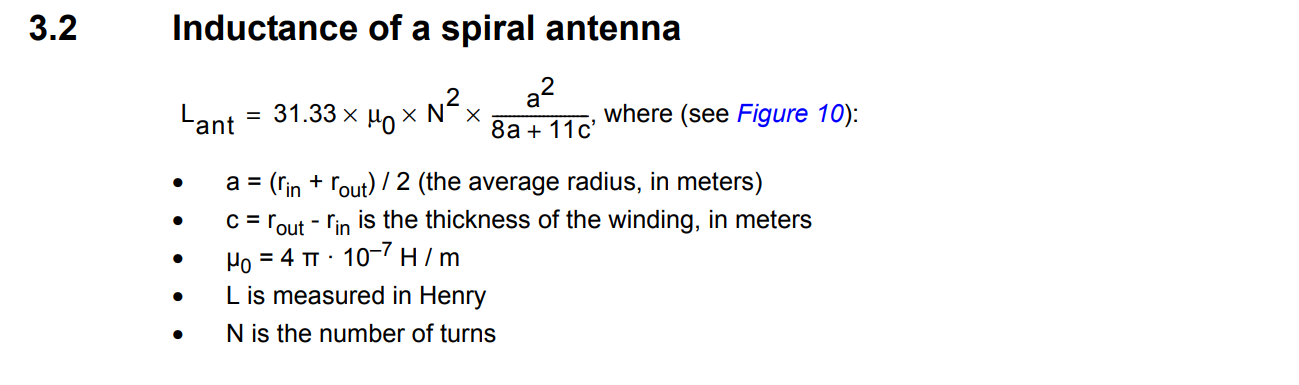
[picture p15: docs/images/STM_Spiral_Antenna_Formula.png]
STM Spiral Formula
    
</p>
<p align="center"><i>STM Spiral Antennas Formula</i></p>

I utilized the [Antenna_Shape_Calculator](./reference/Antenna_Shape_Calculator.xlsx) excel document to calculate the geometric parameters. They were as follows:
* $r_{in} = 17.5mm$
* $r_{out} = 20.5mm$
* $Nant = 6\:turns$
* $L_{calc} = 2.766uH$

### Missing Parameters 
We are not quite ready to complete the design. Looking back at the equivalent circuit, we are still missing a few parameters: antenna capacitance, antenna resistance, and the NFC IC resistance. Typically, these parameters are determined by measuring the actual physical circuit design. For a guide on how to measure these parameters, check out the following link: --> [Guide to designing antennas for the NTAG I2C plus](https://community.nxp.com/t5/NXP-Designs-Knowledge-Base/Guide-to-designing-antennas-for-the-NTAG-I2C-plus/ta-p/1104729).  Nevertheless, we can make some rough estimations by utilizing various tools.

* Antenna resistance - By using a parasitic resistance tool in KiCad, we can calculate this parameter. According to the tool, the parasitic resistance was 1.17 ohms. 
* Antenna capacitance - By utilizing the [NXP NFC Antenna Tool](https://community.nxp.com/t5/NFC/bd-p/nfc/page/4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.) we can roughly estimate this parameter. This tool does not support spiral designs, but we can use the rectangular design to estimate this parameter. According to the tool, the parasitic capacitance was 1.9 pF.
* NFC IC Resistance - Assuming the voltage should drop entirely across the IC, we can consider this resistance to be infinitely large. For our purposes, we will estimate it to be 100k ohms.

<p align="center">
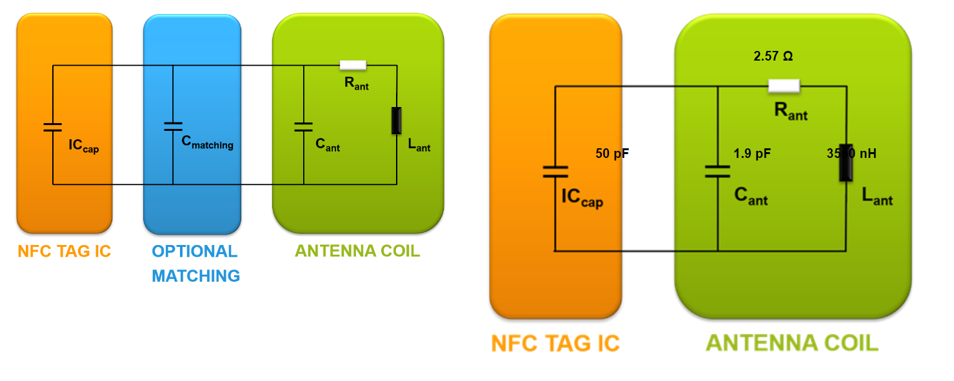
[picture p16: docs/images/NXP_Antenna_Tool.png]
NXP NFC Antenna Tool
    
</p>
<p align="center"><i>NXP NFC Antenna Tool</i></p>

## Simulation
We can now work our way backwards to verify the parameters we calculated above. By rebuilding the equivalent circuit with these parameters in LTSpice, we can verify the resonance frequency. According to the simulation below, the resonance frequency is 13.35 MHz. This should be adequate for NFC; alternatively, we can target an inductance of 2.5-2.6 uH to achieve a resonance frequency that is closer to 13.56 MHz. Furthermore, an optional tuning capacitor can be added to get closer to 13.56 MHz.

<p align="center">
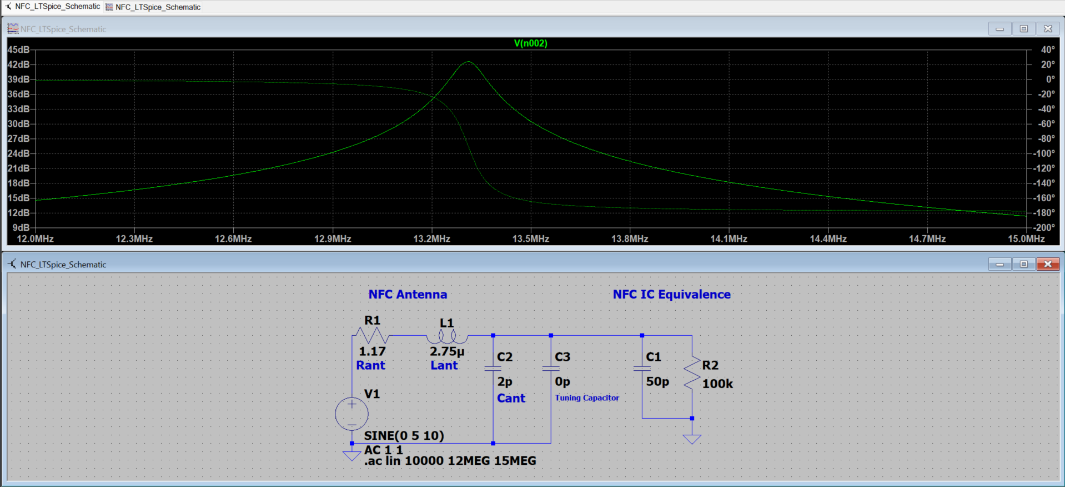
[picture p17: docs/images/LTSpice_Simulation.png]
LTSpice Simulation
    
</p>
<p align="center"><i>LTSpice Simulation</i></p>

I decided to rerun the simulation and redesign the antenna parameters ($D_0 = 39mm$) to target an inductance of 2.576uH. This gives us more headroom to account for any imperfections in the manufacturing process. This allows us to use a tuning capacitor to bring the resonance frequency down and closer to 13.56 MHz.  

<p align="center">
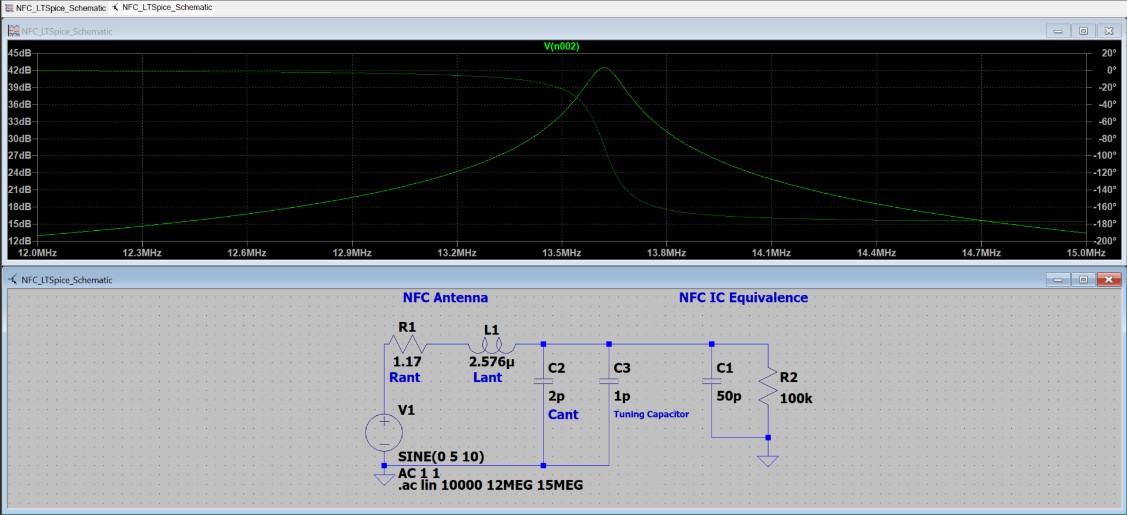
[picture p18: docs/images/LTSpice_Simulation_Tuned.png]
LTSpice Simulation Tuned
    
</p>
<p align="center"><i>LTSpice Simulation with Tuning Capacitor</i></p>

### Electromagnetic Simulation 🧲
Antennas are typically simulated in electromagnetic simulation software. There are various tools available, such as:
* Ansys HFSS - The student edition does not support circuit simulation nor does it support import/export
* Solidworks CST Microwave -  The student edition does not support circuit simulation nor does it support import/export 
* openEMS
* MATLAB Antenna Toolbox

For this design, I ended up simulating it in MATLAB because I did not have access to the non-student versions of HFSS or CST.

#### MATLAB Antenna Toolbox
By utilizing [MATLAB's Antenna Toolbox](https://www.mathworks.com/help/antenna/), we can generate a spiral antenna as well as its S-parameters based on the network-matched design.

<p align="center">
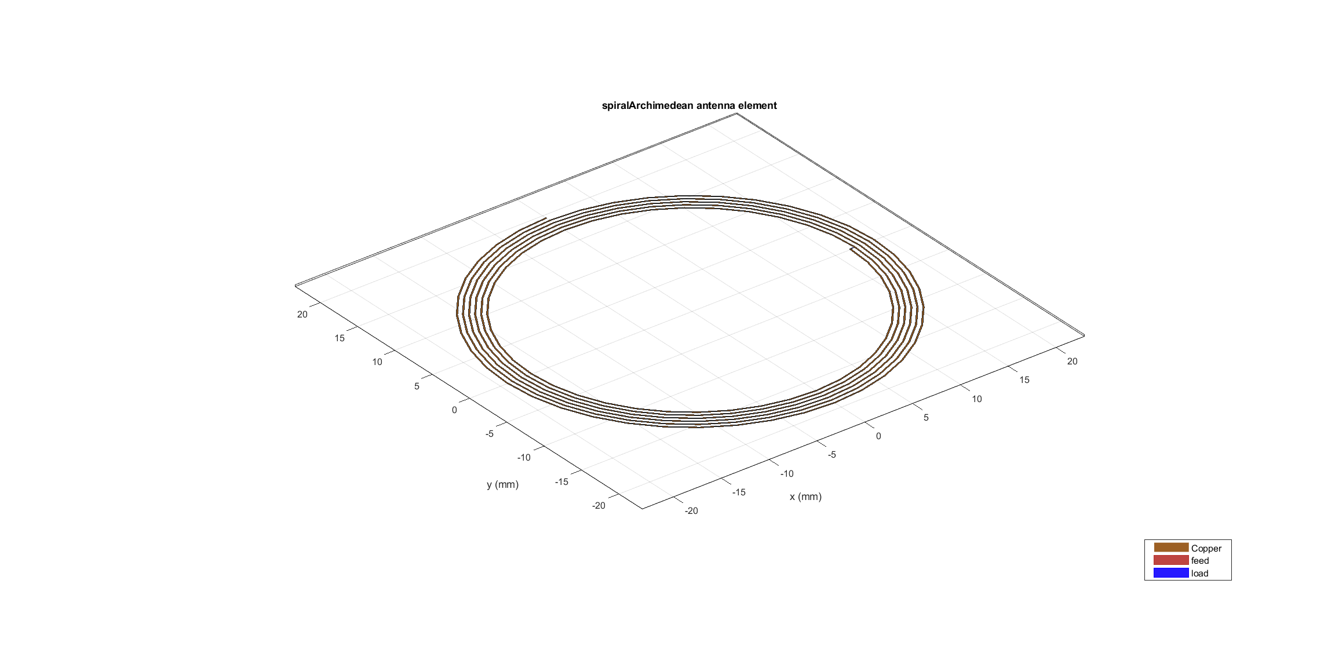
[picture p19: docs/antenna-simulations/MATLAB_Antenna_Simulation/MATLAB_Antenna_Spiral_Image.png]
MATLAB Antenna Simulation
    
</p>
<p align="center"><i>MATLAB Archimedean Spiral</i></p>

<p align="center">
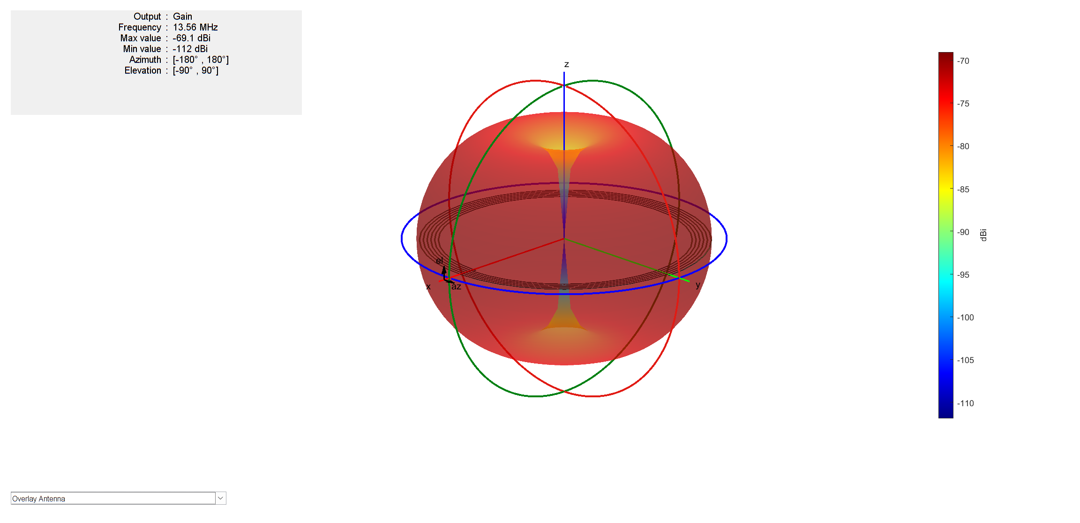
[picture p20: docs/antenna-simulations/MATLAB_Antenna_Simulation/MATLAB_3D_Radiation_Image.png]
MATLAB Antenna Simulation
    
</p>
<p align="center"><i>MATLAB 3D Radiation Pattern</i></p>

<p align="center">
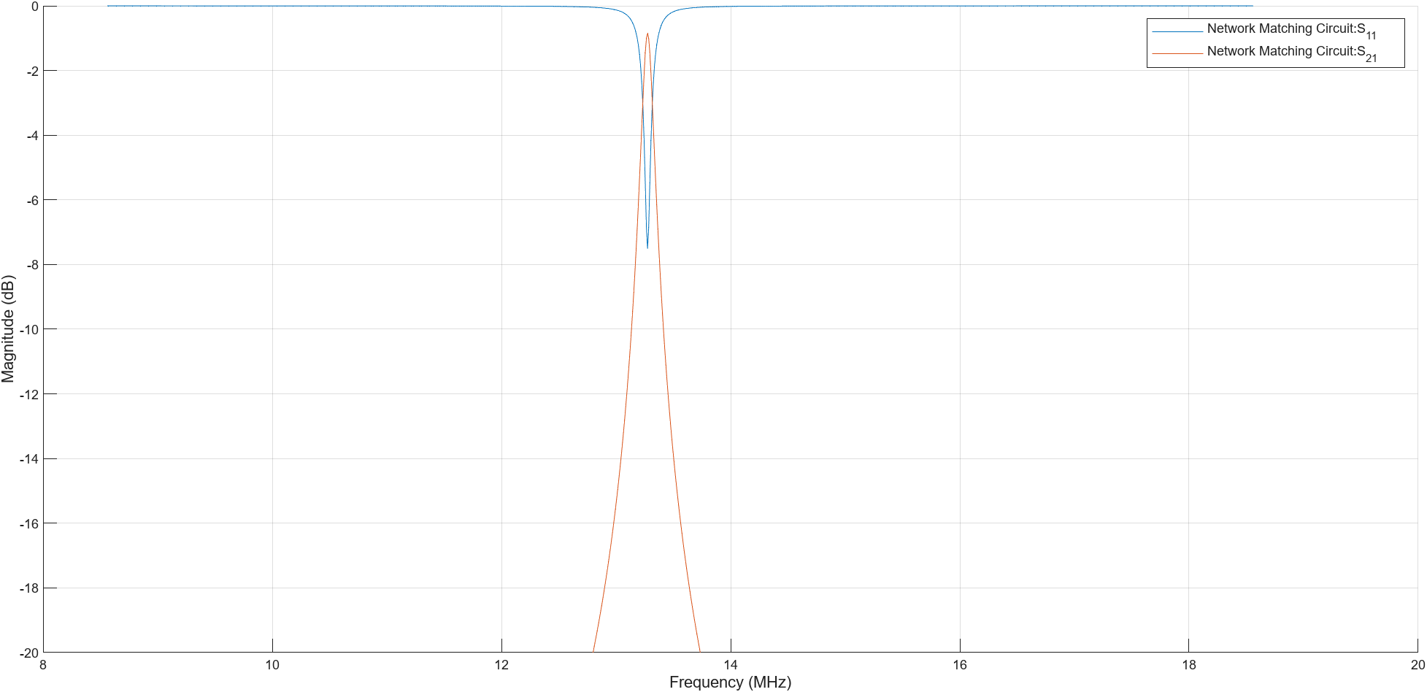
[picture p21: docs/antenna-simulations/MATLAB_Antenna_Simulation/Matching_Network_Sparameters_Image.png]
MATLAB Antenna Simulation
    
</p>
<p align="center"><i>MATLAB Matching Network S-parameters</i></p>

S11 represents the return loss of a device, indicating how much of the input power supplied to the device reflects back to the input port. For an NFC antenna design, it is desired for it to have the lowest gain at at 13.56 MHz. 

## PCB Design
For the final design of the antenna I ended up settling on the following parameters:
* $D_0 = 39mm$
* $t = 35um$
* $w = 300um$
* $g = 300um$
* $Nant = 6\:turns$
* $L_{calc} = 2.576uH$
* $R_{ant} = 1.17\:ohms$
* $C_{ant} = 2pF$
* $Simulated\:resonance\:frequency:\:13.75 MHz$ 
    * *Without Tuning Capacitor*

For the schematic, I borrowed the idea of an LED indicator for the energy harvesting circuit from the [PCB Business Card With NFC](https://www.instructables.com/PCB-Business-Card-With-NFC/). The capacitor is to guarantee operation during RF communication. The resistor value was chosen to limit the current going through the LED. The value was determined by using the following equation:
* $R\:=\:\frac{V_{CC}-V_{LED}}{I_{LED}}=\frac{3.3-2}{0.02} = 65Ω$

<p align="center">
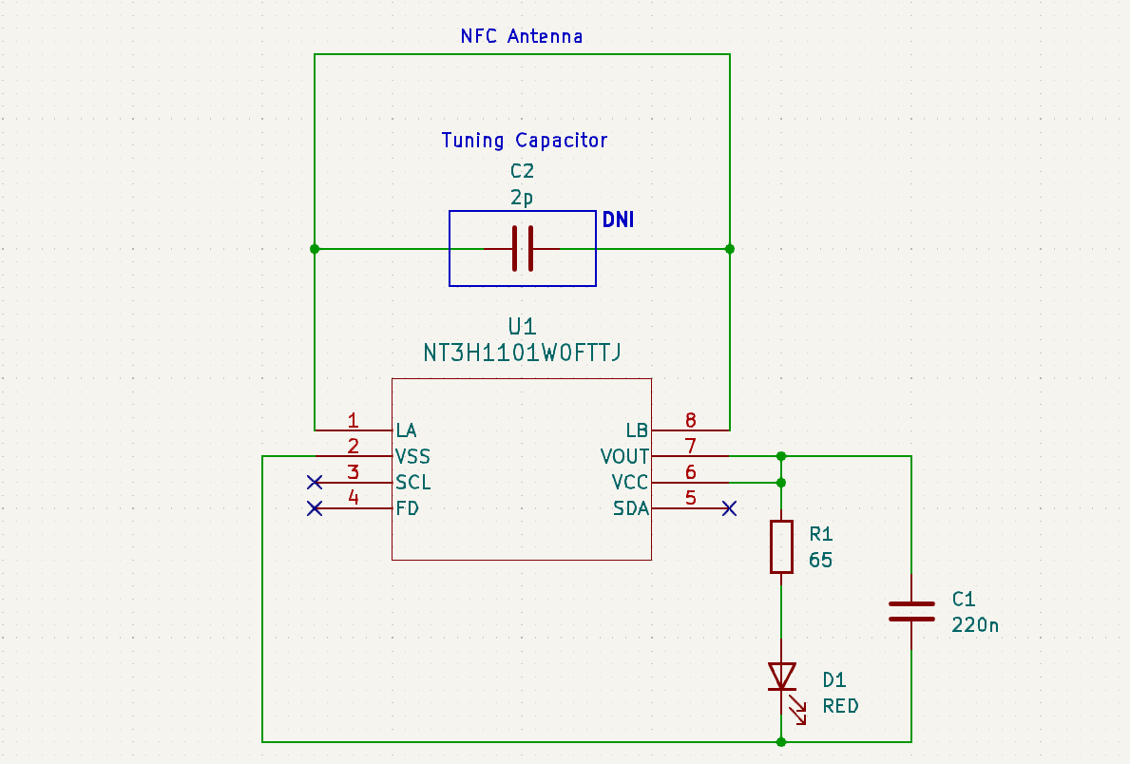
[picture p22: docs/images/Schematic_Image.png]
KiCad Schematic Design
    
</p>
<p align="center"><i>Schematic Design</i></p>
<p align="center">
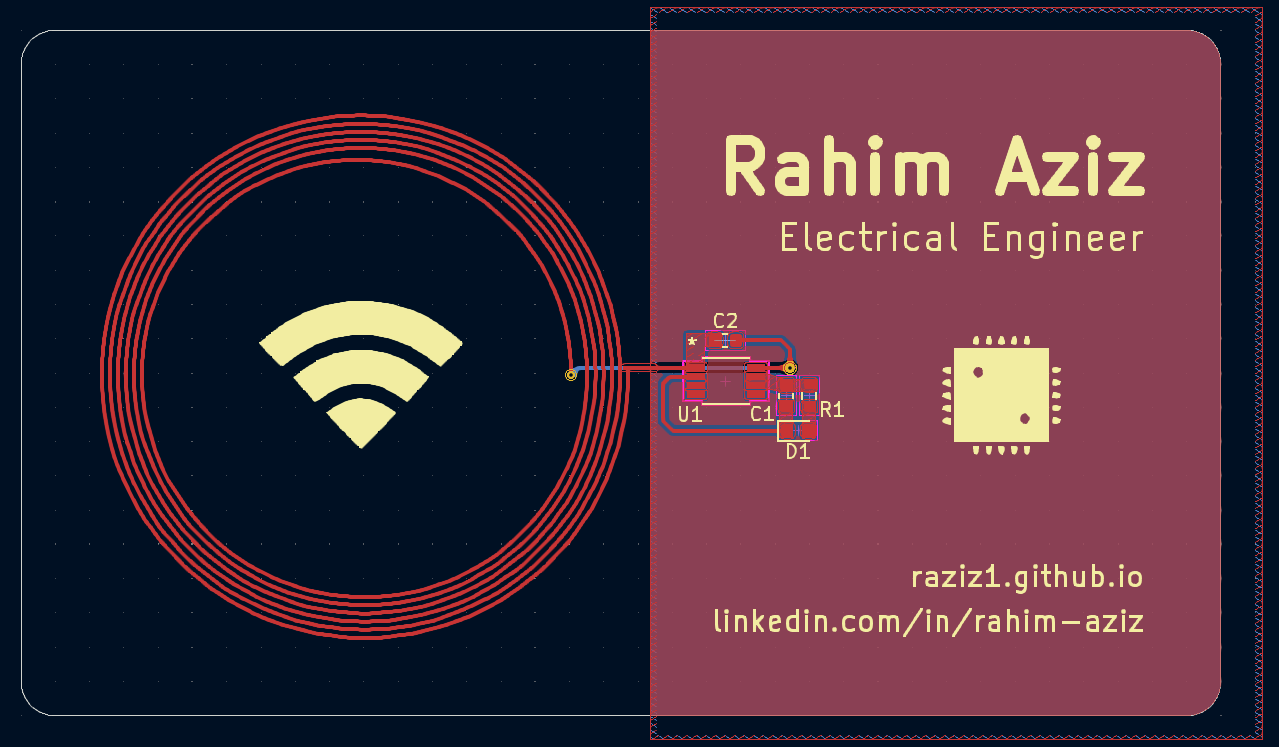
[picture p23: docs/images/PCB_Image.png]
KiCad PCB Design
    
</p>
<p align="center"><i>PCB Design</i></p>

## Final BOM 📃
* [NT3H1101W0FTTJ - IC RFID TRANSP 13.56MHZ 8TSSOP](https://www.digikey.ca/en/products/detail/nxp-usa-inc/NT3H1101W0FTTJ/5347877)
* [150060VS75000 - LED GREEN CLEAR 0603 SMD](https://www.digikey.ca/en/products/detail/w%C3%BCrth-elektronik/150060VS75000/4489906)
* [C0603C224J4REC7867 - CAP CER 0603 220NF 16V X7R 5%](https://www.digikey.ca/en/products/detail/kemet/C0603C224J4REC7867/8643651)
* [CRCW060364R9FKEA - RES SMD 64.9 OHM 1% 1/10W 0603](https://www.digikey.ca/en/products/detail/vishay-dale/CRCW060364R9FKEA/1174533)
* [GRM0335C1E1R5BA01D - CAP CER 1.5PF 25V C0G/NP0 0201 (0603 Metric)](https://www.digikey.ca/en/products/detail/murata-electronics/GRM0335C1E1R5BA01D/4358584)

## Manufacturing 🪛
I ordered the board through PCBWay by using the [KiCAD plugin](https://www.pcbway.com/blog/News/PCBWay_Plug_In_for_KiCad_3ea6219c.html). I assembled and soldered the components on the board myself. 

For the PCBWay specification selection I chose the following options:
* Layers: 2
* Material: FR-4
* FR4-TG: TG130-140
* Thickness: 1.6mm
* Min track/spacing: 5/5mil
* Solder mask: Green
* Silkscreen: White
* Edge connector: No
* Surface finish: HASL with lead
* Via process: Tenting vias
* Finished copper: 1 oz Cu
* Remove product Num: No

<p align="center">
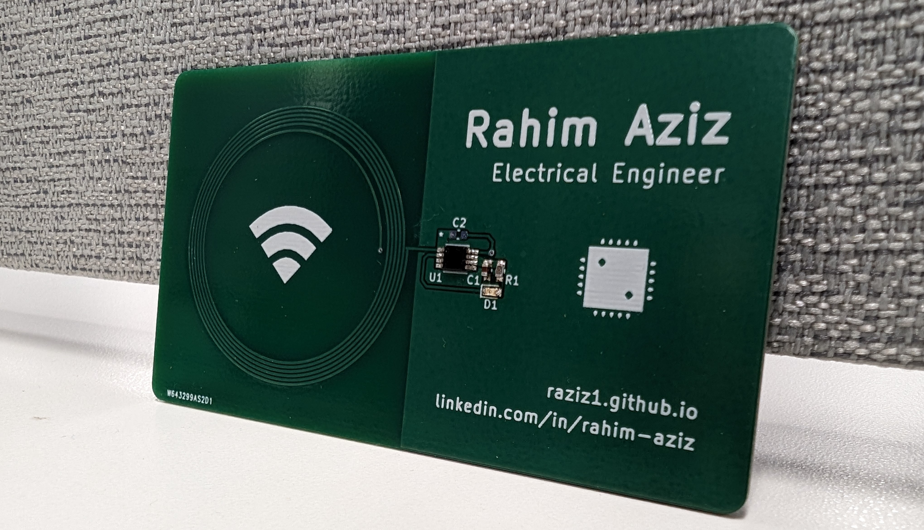
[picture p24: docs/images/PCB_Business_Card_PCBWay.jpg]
PCBWay PCB
    
</p>
<p align="center"><i>Final Product</i></p>

## Programming 💻
Lastly, I programed the IC through the [NFC TagWriter by NXP](https://play.google.com/store/apps/details?id=com.nxp.nfc.tagwriter&hl=en_GB) app.

<p align="center">
    PCB GIF
</p>
<p align="center"><i>PCB in Action!</i></p>

## Characterization 🔬
Finally, I wanted to characterize the response of the circuit using my Analog Discovery 2 - USB oscilloscope. In particular, I aimed to characterize and visualize the difference in responses when the circuit had and didn't have a tuning capacitor.

### No Tuning Capacitor

The first order of business was to utilize the network analyzer feature on the Analog Discovery 2. By attaching the wave generator on one end of the antenna and probing on the other we could sweep through various frequencies and observe the circuits response.

<p align="center">
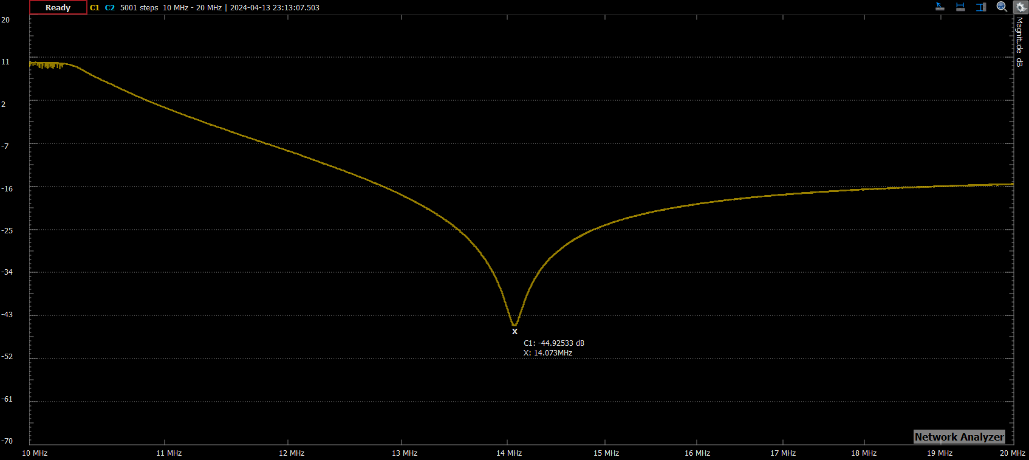
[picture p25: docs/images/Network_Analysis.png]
Network Analyzer
    
</p>
<p align="center"><i>Network Analyzer</i></p>

The above graph describes the S11 parameter, which represents the return loss of a device, indicating how much of the input power supplied to the device reflects back to the input port. We observe that at 14 MHz, the graph dips to a gain of -44.9 dB. This indicates that at 14 MHz, the magnitude of the reflected signal is lower than the magnitude of the incident signal. This implies that the antenna is absorbing the incident energy rather than reflecting it back towards the source. This response closely matches what we simulated previously in LTspice and MATLAB. For an NFC antenna, this behavior is desirable at 13.56 MHz. We can generate a graph with a dip closer to 13.56 MHz by including the tuning capacitor!

<p align="center">
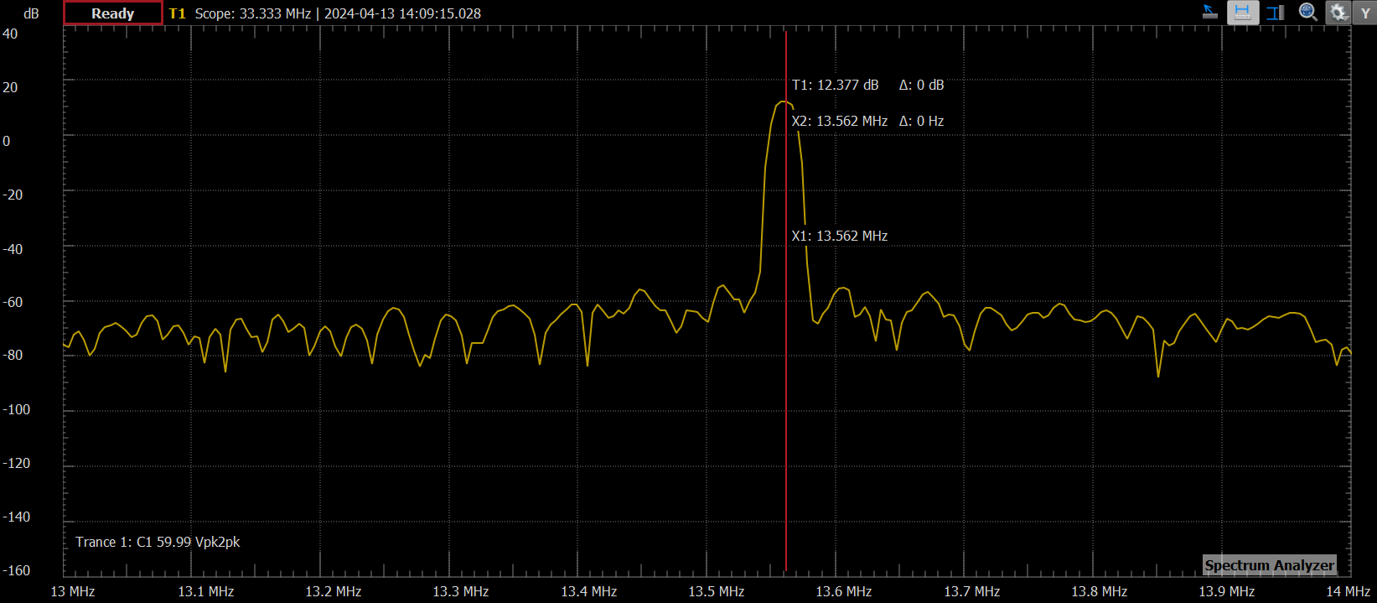
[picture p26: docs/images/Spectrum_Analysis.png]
Spectrum Analyzer
    
</p>
<p align="center"><i>Spectrum Analyzer</i></p>

Lastly, during the operation of the circuit, we can utilize the spectrum analyzer to observe the magnitude of the incoming signal. Keep in mind that this circuit doesn't contain a tuning capacitor. This was achieved by probing both ends of the antenna. Once a phone was brought within operating distance, we could see that the antenna contained a signal with a magnitude of 12.37 dB at 13.56 MHz.

### Tuning Capacitor Included (3.9pF)

By introducing a tuning capacitor with a value of 3.9pF, I was able to adjust the circuit's response to achieve resonance closer to the NFC standard of 13.56 MHz. Below is the graph produced by the network analyzer. We can see that this time the graph dips at a frequency of 13.555 MHz with a gain of -44.34 dB.

<p align="center">
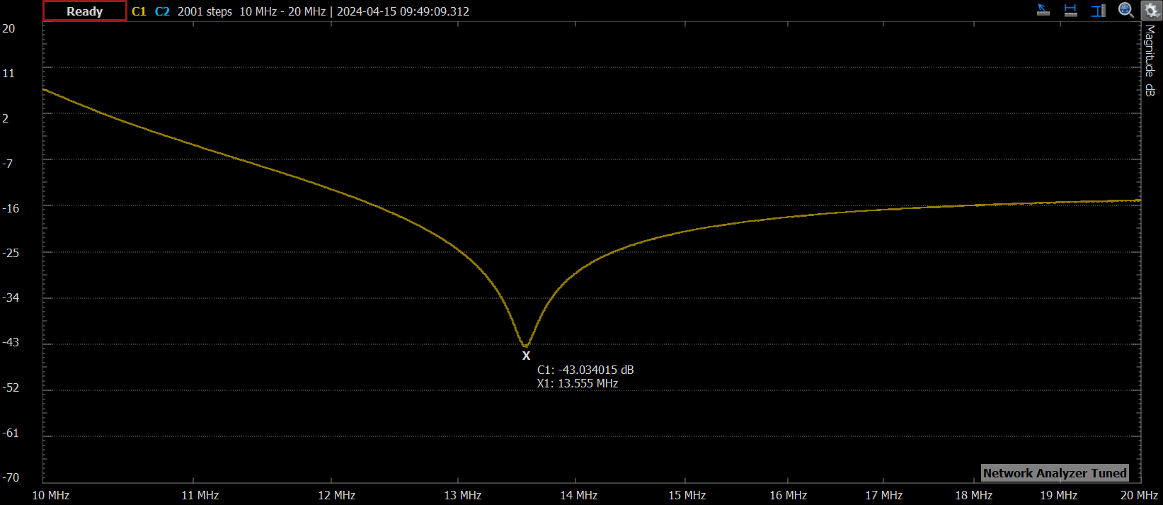
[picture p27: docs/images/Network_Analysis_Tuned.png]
Network Analyzer Tuned
    
</p>
<p align="center"><i>Network Analyzer</i></p>

<p align="center">
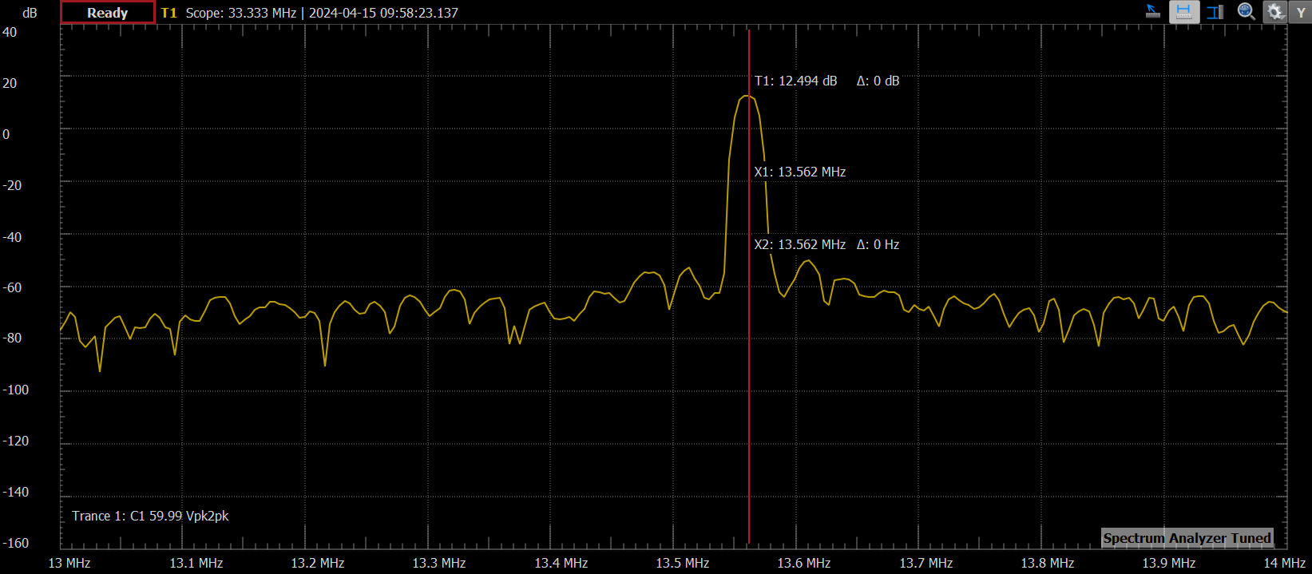
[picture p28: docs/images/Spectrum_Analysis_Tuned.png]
Spectrum Analyzer Tuned
    
</p>
<p align="center"><i>Spectrum Analyzer</i></p>

Utilizing the same process as the previous spectrum analysis, we can observe that the antenna contained a signal with a magnitude of 12.494 dB at 13.562 MHz.

### Poorly Tuned NFC Antenna
By introducing a really large tuning capacitor with a value of 15pF, we can adjust the circuit's response to achieve resonance at 12.5 MHz. Given the poorly tuned antenna, we expect to either see that the NFC capabilities cease to work or that the magnitude of the NFC signal is extremely weak. We can quantify this by utilizing the same spectrum analysis technique as used in the previous examples.

<p align="center">
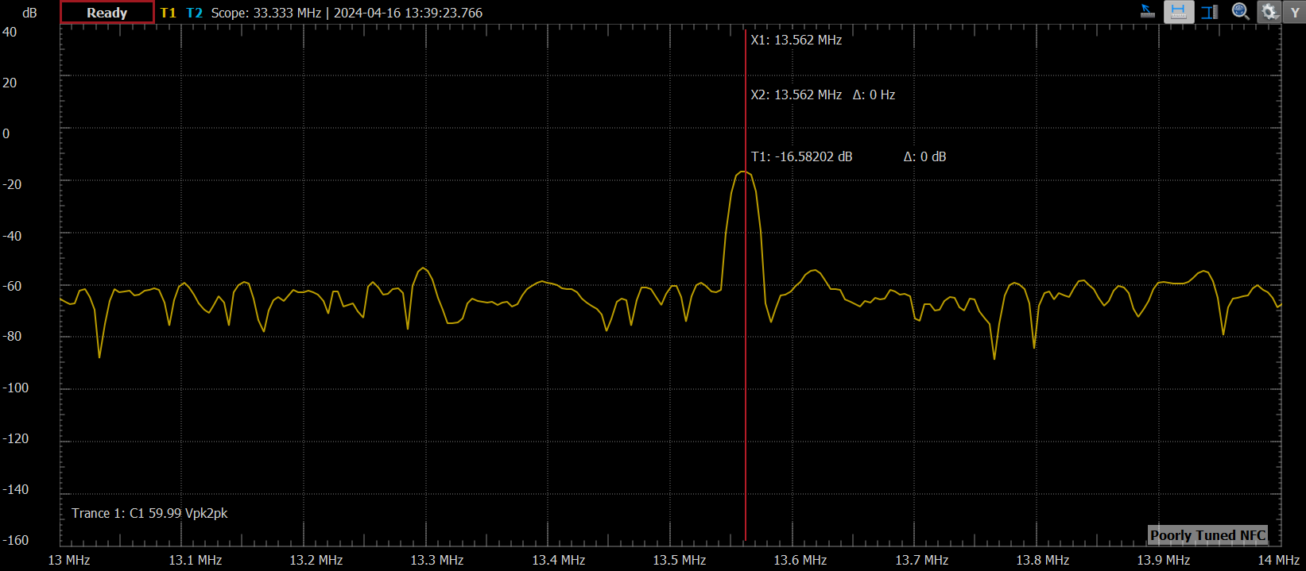
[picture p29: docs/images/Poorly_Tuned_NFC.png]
Spectrum Analyzer Poorly Tuned
    
</p>
<p align="center"><i>Spectrum Analyzer of Poorly Tuned Antenna</i></p>

With the poorly tuned antenna, the NFC capabilities continued to work. However, it did require the phone to be slightly closer to the antenna. Additionally, based on the above graph, we can see that the magnitude of the NFC signal (13.56MHz) is significantly weaker than in previous examples.

## NFC Protocol
By utilizing the Analog Discovery 2 oscilloscope feature, I was able to capture a snippet of an NFC transmission. This was done by probing the antenna during NFC operation. The NFC protocol is extremely complicated, and therefore, it is difficult to decipher what this transmission is. You can click on the following link to learn more about the [NFC transmission protocol](https://scdn.rohde-schwarz.com/ur/pws/dl_downloads/dl_application/application_notes/1ma182/1MA182_5E_NFC_WHITE_PAPER.pdf).

<p align="center">
    NFC Transmission
</p>
<p align="center"><i>NFC Transmission</i></p>

# Resources
* [Guide to designing antennas for the NTAG I2C plus
](https://community.nxp.com/t5/NXP-Designs-Knowledge-Base/Guide-to-designing-antennas-for-the-NTAG-I2C-plus/ta-p/1104729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)
* [PN7160 antenna design and matching guide](https://www.nxp.com/docs/en/application-note/AN13219.pdf)
* https://github.com/shawnalexsony/Business_Card_PCB/tree/main
* [PCBWAY Custom Design Rules Templates](https://www.pcbway.com/pcb_prototype/PCB_Design_Rule_Check.html?currency=1)

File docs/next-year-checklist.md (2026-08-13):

# Reusing these cards for a new rush

Read this first if you've inherited the repo and rush is coming.

## The important asymmetry

**The brother card is year-independent. The PNM card is not.**

Nothing on the brother card names a year, a date, or an event. The rush link lives in
the chip, not the silkscreen. So brother cards can be **reordered as-is and
reprogrammed** — and because the 2025 tags were left **unlocked**, any surviving 2025
cards can simply be rewritten instead of replaced.

The PNM card prints the entire 2025 schedule. It needs the dates and events retyped
every single year. That's the annual work.

## Do this once, and the brother cards stop needing work forever

**Set up a permanent redirect and program the tags with that**, instead of writing a
destination URL directly onto the chips.

The 2025 cards were programmed with a URL that has already gone stale — the chapter site
changed. Pick a stable path you own (`beta.mit.edu/rush`, say), point the tags at it, and
have it redirect to whatever this year's rush content is. Then future years change one
line on the website and touch zero hardware, and a card printed in 2025 still works in
2030.

The chapter has decided to go this way. Details and the field to record the chosen URL
are in [`programming-the-tag.md`](./programming-the-tag.md). **Doing this before the next
batch is programmed is the single highest-leverage thing on this page.**

## If you're only doing the minimum

1. **Brother cards** — reorder from
   [`../brother-card/fab/2025-07-30_release/`](../brother-card/fab/2025-07-30_release/)
   plus the two files in
   [`../brother-card/fab/jlcpcb-assembly/`](../brother-card/fab/jlcpcb-assembly/) for
   assembly, then write the redirect URL to each
   ([`programming-the-tag.md`](./programming-the-tag.md)). No KiCad needed at all.
   Remember: **1 mm thickness, blue mask** — see
   [`reordering.md`](./reordering.md).
2. **PNM cards** — retype the schedule (below), re-export, order. **1 mm, green mask.**
3. Or, if you have leftover 2025 brother cards: **just rewrite their tags.** No order at
   all.

## Updating the PNM card

Open `pnm-card/PNM_Rush_Card.kicad_pcb` in Pcbnew. Everything is text objects and
artwork footprints on the two silkscreen layers; there is no schematic to keep in sync
and no netlist to update. Work directly on the board.

What to change:

- [ ] **Day headings.** Eight of them: four on `F.SilkS`, four on `B.SilkS`.
- [ ] **Event lists.** One text object per day, with `\n` line breaks between events.
      Edit the whole block in one text-properties dialog.
- [ ] **The van pickup number** — currently `(617) 715-2762`. Confirm it's still the
      house line.
- [ ] **`beta.mit.edu`** if the chapter's web address ever changes.
- [ ] **Fix the 2025 typo, don't inherit it.** The 2025 card says
      **"Saturday, August 31"** for what was actually a **Sunday**. It's preserved in
      the source deliberately so the archive matches the physical card. Don't
      propagate it — and check every day-of-week against a real calendar, since this
      is exactly the mistake that survives proofreading.

Then:

- [ ] **Run DRC.** Expect only `text_thickness` warnings. If you get anything else,
      you moved something you didn't mean to.
- [ ] **Watch text size.** More events per day means smaller or thinner text, and the
      silkscreen strokes are already below KiCad's 0.15 mm minimum. Past a point the
      fab can't resolve them. If you're cramming, ask the vendor for their real
      minimum line width rather than guessing.
- [ ] **Render and read it.** Cheapest possible proofread:
      ```sh
      export PATH="/Applications/KiCad/KiCad.app/Contents/MacOS:$PATH"
      kicad-cli pcb render --side top    --width 2400 --height 1500 --quality high -o /tmp/front.png pnm-card/PNM_Rush_Card.kicad_pcb
      kicad-cli pcb render --side bottom --width 2400 --height 1500 --quality high -o /tmp/back.png  pnm-card/PNM_Rush_Card.kicad_pcb
      ```
      Have someone who *didn't* type the dates check them against a calendar.
- [ ] **Export gerbers to a new dated folder**, e.g.
      `pnm-card/fab/2026-08-01_release/`. Never overwrite `2025-07-30_release/` — it's
      the record of a physical object that exists.
- [ ] **Commit before ordering.** The commit that matches an order is what makes a
      reorder possible in three years.

## Lead time, from what actually happened in 2025

| Date (2025) | Event | Gap |
|---|---|---|
| Jul 30 | Gerbers plotted | |
| **Aug 6** | Order `10486412A` placed at JLCPCB | +7 days of sitting on it |
| Aug 9 | Brother cards finished (50, incl. assembly) | **3 days** |
| Aug 11 | PNM cards finished (350) | **5 days** |
| **Aug 30** | Rush week begins | ~3 weeks of slack |

**Order to rush: 24 days**, of which fabrication was only 3–5. Three weeks total is
comfortable; two is tight but feasible. Full detail in
[`order-history.md`](./order-history.md).

The steps that will actually bite you:

| Step | Notes |
|---|---|
| Finalise the schedule | The real blocker. You can't print a card before events are locked. |
| Fab + assembly | 3–5 days at JLCPCB in 2025. Cheap shipping tiers add far more delay than fab does. |
| **Shipping + customs** | The leg that varies most, and the one that cost the most — see the budget note below. |
| **Depaneling** | If you skip paying for it, someone snaps 50 edge rails off by hand. Budget the hour, or tick the box. |
| Tag programming | ~15 s per card, but **per card**. Easy to forget until the night before — and unnecessary entirely if you set up the redirect above. |

### Budget ≈ $400, not $110

The 2025 order's PCB line items came to $109.80, but **about $400 was actually paid** once
assembly, components, shipping, and US import tariffs were counted — with freight and
tariffs taking a significant share. **Apply a 3–4× multiplier to whatever JLCPCB's order
page quotes you**, and keep both cards on a single shipment, since duty and freight are
largely per-shipment rather than per-board. Details in
[`order-history.md`](./order-history.md).

### Take photos this time

**No photographs of the 2025 cards were ever taken.** The only visual record of either
card is the set of CLI renders in [`renders/`](./renders/) — accurate about geometry and
colour, but they can't show solder quality, real silkscreen legibility, the snapped rail
edge, or the LED lit during a tap.

When the next batch arrives: shoot front and back of both cards, one mid-tap with `D1`
lit, and a few from rush week of cards actually being handed out. Put them in
`docs/photos/` and link them from the card READMEs. It costs five minutes and it's the
one thing this archive can't reconstruct after the fact.

## Ideas worth considering

- **Bring the doodle border back.** [`../brother-card-v1/`](../brother-card-v1/) had a
  doodle frame — gamepads, gears, a card hand, books, a handshake, the dome — that was
  cut before production. It's still in the library as `btp:doodles`, so restoring it is
  a copy-paste, not a redraw. It's the most charming artwork in this repo and it never
  got made.
- **Order more brother cards than you think you need.** Only 50 were made in 2025 versus
  350 PNM cards. The PCB cost was $23.70 — the real cost is assembly and the per-part
  feeder fees on four "Extended" parts, which are *fixed*, so the marginal cost per card
  drops fast with quantity. 50 → 200 costs far less than 4×.
- **Try one card with an exposed-copper finish.** The artwork is already copper-vs-mask;
  ordering a small batch with no mask over the crest half, or in ENIG so the copper reads
  gold, would look striking. Cheap experiment on a 50-piece run.
- **Put an NFC tag in the PNM card too.** It's currently a passive flyer. Adding the
  brother card's circuit would let a PNM tap their own card to reach the rush link —
  arguably higher value than a brother tapping *at* them. Costs five parts and
  assembly labour on the higher-volume card, so it's a real tradeoff.
- **Use a redirect, not a direct URL.** Program the tags with a short link you control
  (e.g. a `beta.mit.edu` path that redirects) rather than a deep link. Then next year's
  cards need no reprogramming at all — you just change where the redirect points. This
  is the single highest-leverage change available: it would make the brother cards
  genuinely permanent.

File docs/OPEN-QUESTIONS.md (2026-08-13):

# Open questions

What still isn't recorded anywhere. Most of the original list has been closed — the
resolved items are kept at the bottom so nobody re-investigates them.

If you close one, edit the answer into the relevant doc and move the entry down here.

---

## Still open

Only two, and neither blocks a reorder.

### 1. Which app programmed the tags, precisely

Known: it was an Android device, and iPhone reportedly didn't work.

**Best explanation for the iPhone failure:** NFC TagWriter by NXP is **Android-only** —
it isn't in the App Store, so there was nothing to install. A second likely factor is
that the iPhone's NFC antenna sits at the **top edge of the back**, so aiming at the
middle of the phone silently fails. iPhones (7+, iOS 13+) *can* write NDEF with a Core
NFC app like NFC Tools.

Low stakes — the Android path is documented and works. Worth a sentence if anyone
remembers the specific app.

→ [`programming-the-tag.md`](./programming-the-tag.md)

### 2. Upstream licensing

[Raziz1/PCB_Business_Card](https://github.com/Raziz1/PCB_Business_Card) has **no license
file**. This repo reproduces its `README.md` verbatim as [`nfc-theory.md`](./nfc-theory.md)
along with its figures, simulations, and reference documents, with attribution throughout.

Absent a license, upstream retains all rights by default. Attribution is the right thing
to do and normal fork etiquette, but it isn't the same as permission — and this repo is
public.

**Suggested fix:** open an issue or email Rahim Aziz asking him to add a license (MIT or
CC-BY would both suit), or for explicit permission to redistribute. One message, and the
ambiguity is gone. If he'd rather not, the fallback is stripping `nfc-theory.md` and the
inherited `images/` + `antenna-simulations/` assets down to links.

**Already handled:** Beta's own original work is MIT licensed, and [`../LICENSE`](../LICENSE)
states explicitly which files that does *not* cover — upstream's material, the NXP/ST
application notes, and the fraternity's insignia.

---

## Resolved

### ~~Photographs of the real cards~~ — none were ever taken

Confirmed: **no photographs of either finished Beta card exist.** This isn't a matter of
finding them; they were never shot. Not recoverable, and no further searching is warranted.

**Consequence:** the CLI renders in [`renders/`](./renders/) are the *only* visual record
of these cards. They're geometrically faithful and now in the correct as-ordered mask
colours, but they cannot show solder quality on the XQFN8, real silkscreen legibility at
1 mm, how the bare-copper artwork catches light, the snapped edge where the assembly rails
came off, or `D1` lit mid-tap.

**Action moved forward, not closed:** the next batch should be photographed on arrival.
[`next-year-checklist.md`](./next-year-checklist.md) has this as an explicit step — it's
the one thing this archive cannot reconstruct after the fact.

### ~~Assembly and component cost~~ — total known, breakdown isn't

**About $400 was paid for the whole order**, against $109.80 of documented PCB line items.
The remaining ≈$290 covers assembly, components, shipping, and **US import tariffs**, with
delivery and tariffs taking a significant share. The split among those four is not
recorded, and chasing it further isn't worth it.

The planning number — **budget 3–4× the PCB quote** — is what actually mattered, and it's
now in [`reordering.md`](./reordering.md) and
[`next-year-checklist.md`](./next-year-checklist.md).

### ~~The rush URL written to the NFC chips~~ — moot, and superseded

The 2025 tags were programmed with a URL that has since gone stale: the chapter website
changed and that link no longer points anywhere meaningful. Recovering the exact string
would be archaeology with no payoff.

**What replaced the question:** the chapter is moving to programming the tags with a
**permanent redirect it controls** (a stable `beta.mit.edu/rush`-style path) so that
future years change the redirect target on the website and never reprogram hardware.
That makes the historical URL irrelevant by design. See
[`programming-the-tag.md`](./programming-the-tag.md), which has a field to record the
redirect URL once chosen.

### ~~Were the tags locked read-only?~~ — No

Confirmed unlocked. Every surviving 2025 brother card can be rewritten, so the
"brother cards are year-independent" claim in
[`next-year-checklist.md`](./next-year-checklist.md) holds, and the redirect plan above is
viable on existing hardware.

### ~~Fab vendor, quantity, cost, turnaround~~ — JLCPCB, order `10486412A`

50 brother cards at $23.70 and 350 PNM cards at $86.10, **≈$400 paid in total**; ordered
Aug 6 2025, finished Aug 9 and Aug 11. Full record in
[`order-history.md`](./order-history.md), reconstructed from screenshots and JLCPCB's own
CAM job records.

Bonus discoveries from that record, all of which contradicted earlier assumptions:

- **Both cards are 1 mm thick**, not the 1.6 mm in the KiCad files.
- **The brother card is blue**, not green. The PNM card is green.
- JLCPCB adds **two 10 mm edge rails** to the brother card for assembly, V-scored off,
  and **depaneling was not paid for** — the cards arrived with rails attached.
- The repo's `fab/…_release/` folders are **byte-identical to what JLCPCB received**.

### ~~Hand-assembled or machine-assembled?~~ — Machine, by JLCPCB

Standard PCBA, top side, 50 units, high-temp paste, with JLCPCB-added edge rails and
fiducials. The earlier guess of hand-soldering (inferred from a placement spreadsheet) was
wrong. This also defuses the concern about the XQFN8's 0.5 mm pitch — a pick-and-place
doesn't care.

### ~~What `C2`, the tuning capacitor, actually was~~ — 2.0 pF

`0603CG2R0C500NT`, 2.0 pF C0G 50 V, JLCPCB `C1650`. This matches the `2p` in the
schematic. Upstream's 3.9 pF (measured) and 1.5 pF (parts list) figures were for *their*
board geometry. The Beta cards shipped with 2.0 pF and worked — reorder with it.

The full as-built BOM with manufacturer part numbers and JLCPCB catalogue codes is in
[`order-history.md`](./order-history.md) and
[`../brother-card/fab/jlcpcb-assembly/`](../brother-card/fab/jlcpcb-assembly/).

### ~~Solder mask and silkscreen colours~~ — Blue and green, both white silkscreen

Brother card **blue**, PNM card **green**, white silkscreen on both, ink-jet printed. The
renders in this repo now reflect this. Confirmed independently from the order pages and
JLCPCB's CAM records.

Unchanged and worth restating: the two-tone effect on each card is **bare copper under a
single mask colour**, not two mask colours.

### ~~Surface finish~~ — resolved as far as it matters

The order page for the brother card says HASL **with lead**; JLCPCB's CAM record for the
same product says **lead-free**. JLCPCB requires lead-free finish on assembled boards,
which is the likely explanation. The PNM card says leaded in both places. No action
needed, but don't be surprised if a reorder quotes differently once assembly is added.

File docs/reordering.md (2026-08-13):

# Getting more cards made

The 2025 run is fully documented in [`order-history.md`](./order-history.md) — vendor,
prices, quantities, dates, the real part numbers, and the gotchas. This page is the
short operational version.

## The one rule

**Order from the `fab/` folders, not from a fresh KiCad export.**

| Card | Upload this |
|---|---|
| Brother card | [`../brother-card/fab/2025-07-30_release/`](../brother-card/fab/2025-07-30_release/) |
| PNM card | [`../pnm-card/fab/2025-07-30_release/`](../pnm-card/fab/2025-07-30_release/) |

Those folders were **byte-compared against the files JLCPCB actually received** in 2025
and are identical. Uploading them reproduces the 2025 cards exactly.

Re-exporting from source is not equivalent: replotting the unmodified brother card in
KiCad 10.0.5 produces different zone-fill and teardrop geometry than the KiCad 9.0.2
release set. The fill algorithm changed between versions, and this artwork *is* copper
zones. Re-export only when you've genuinely changed the design — then write it to a new
dated folder and treat it as a new revision.

## What the 2025 run cost — budget $400, not $110

| Line | Amount |
|---|---|
| Brother card PCBs (50, blue, assembled) | $23.70 |
| PNM card PCBs (350, green, bare) | $86.10 |
| **PCB subtotal** | **$109.80** |
| Assembly + components + shipping + **tariffs** | **≈ $290** |
| **Total actually paid** | **≈ $400** |

**The order-page price was roughly a quarter of the final cost.** Delivery and US import
tariffs on Chinese-manufactured goods took a significant share of that $290, alongside
assembly labour and the parts themselves. The exact split isn't recorded.

Two things follow for planning:

- **Quote with a 3–4× multiplier on whatever JLCPCB's PCB page shows you**, or you will
  badly under-budget. This is the single most useful number on this page.
- **Order in fewer, larger shipments.** Freight and duty are largely per-shipment rather
  than per-board, so splitting a run across two orders roughly doubles the part of the
  bill that hurt most. Both cards went out on one order in 2025 — keep doing that.

Blended, ≈$400 for 400 cards is **~$1 per card**, which is still cheap for a PCB you hand
to someone. But the 50 brother cards absorb essentially all the assembly and component
cost, so their real unit cost is many times the PNM cards'. Four of the five parts are
JLCPCB **"Extended"** parts carrying a per-part feeder setup fee — a *fixed* cost, so the
per-card penalty shrinks fast with quantity. If you're near the decision, ordering 200
brother cards instead of 50 costs far less than 4×.

Fabrication took **3 days** (brother, including assembly) and **5 days** (PNM). Order to
rush was 24 days — but note shipping is the leg that varies most, and the cheap freight
tiers that keep cost down are the slow ones. Three weeks is comfortable; two is tight.

## Settings to select — including three that are easy to get wrong

Vendor: **JLCPCB**, order `10486412A` in 2025.

| Setting | Brother card | PNM card |
|---|---|---|
| Layers | 2 | 2 |
| Material | FR-4 | FR-4 TG135 |
| **Thickness** | **1 mm** ⚠️ | **1 mm** ⚠️ |
| **Solder mask** | **Blue** ⚠️ | **Green** ⚠️ |
| Silkscreen | White, ink-jet | White, ink-jet |
| Outer copper | 1 oz | 1 oz |
| Surface finish | HASL (lead-free when assembled) | HASL with lead |
| Via covering | Tented | Tented |
| Electrical test | Flying probe, random | Flying probe, random |

### ⚠️ 1. Thickness: set 1 mm, don't accept the default

**Every KiCad file in this repo says 1.6 mm. Both cards were ordered at 1 mm.** Thickness
is an order-page dropdown that isn't carried in the gerbers, so nothing will warn you.
1 mm is the right choice for a card people put in a wallet — 1.6 mm feels like a circuit
board. Accept the default and you'll get visibly chunkier cards than the 2025 run.

### ⚠️ 2. Colours: the cards are not both green

**Brother card = blue mask. PNM card = green mask.** Both white silkscreen. One mask
colour each — the two-tone effect on each card is **bare copper under a single mask**, so
never order "two-colour mask". On the blue card, the copper half reads blue-violet.

### ⚠️ 3. PNM card: confirm the outline is routed

The PNM card's outline is an **octagon** (chamfered corners), which must be **routed**, not
sheared or V-scored. JLCPCB handled it correctly in 2025 — its production set for that
card has no V-cut layer at all. Some cheap tiers restrict or surcharge non-rectangular
outlines, so confirm it's priced as a routed profile rather than silently squared off.

## Ordering assembly for the brother card

The 2025 brother cards were **machine-assembled by JLCPCB**, top side only, 50 units.
Upload with the gerbers:

- [`../brother-card/fab/jlcpcb-assembly/jlcpcb-bom.csv`](../brother-card/fab/jlcpcb-assembly/jlcpcb-bom.csv)
- [`../brother-card/fab/jlcpcb-assembly/jlcpcb-cpl.csv`](../brother-card/fab/jlcpcb-assembly/jlcpcb-cpl.csv)

Both are already in JLCPCB's column format. See that folder's
[README](../brother-card/fab/jlcpcb-assembly/) for the catalogue codes worth pasting in.

### The bill of materials, as actually ordered

| Ref | Part | JLCPCB code |
|---|---|---|
| `U2` | NT3H2111W0FHKH — NTAG I²C plus, XQFN8 | `C710403` |
| `C1` | CL10B224KA8NNNC — 220 nF 0603 X7R | `C21120` (Basic) |
| `C2` | 0603CG2R0C500NT — **2.0 pF** 0603 C0G 50 V | `C1650` |
| `R1` | 0603WAF649JT5E — **64.9 Ω** 1% 0603 | `C23224` |
| `D1` | LTST-C190KRKT — red 0603 | `C94869` |

**`C2` is settled: 2.0 pF.** Earlier docs in this repo flagged it as uncertain because
upstream used 3.9 pF and listed 1.5 pF. Those were upstream's board. The Beta cards
shipped with 2.0 pF and worked — reorder with it.

### Pay for depaneling

JLCPCB adds **two 10 mm edge rails** to the brother card for assembly (which is why the
order dimension reads 88.9 × 70.8 mm instead of 88.9 × 50.8 mm), carrying the fiducials
and SMT tracking QR code. In 2025, **"Depanel boards & edge rail before delivery" was set
to No**, so 50 cards arrived with rails attached and someone snapped each one off along a
V-score, with "Deburring/Edge rounding" also off.

**Tick depaneling next time.** It's cheap, and it's the difference between a clean card
and two rough edges on something you hand to strangers. The QR/tracking marks live on the
rails, so they disappear with them — a good property to keep if you change the panel.

### Consider removing the order number

Both products were ordered with **Mark on PCB: Order Number**. On the brother card that
folded into the marks on the rails, so the card faces stayed clean. **The PNM card has no
rails, so it likely carries a small JLCPCB order number on a face.** If that bothers you,
choose "Remove order number" (small surcharge) or specify a location.

### Hand assembly, if you ever need it

Not necessary — JLCPCB assembles these fine — but if you ever do it yourself, the XQFN8
is 1.6 × 1.6 mm at 0.5 mm pitch with no exposed pad: hot air and generous flux, or paste
and a hotplate. [`../brother-card-v1/`](../brother-card-v1/) used a pin-compatible
**TSSOP-8** version of the same NTAG family that is far friendlier to an iron.

## After assembly

Every brother card needs its NFC tag written before it goes out —
[`programming-the-tag.md`](./programming-the-tag.md). ~15 seconds per card with an Android
phone, but it's per card, and it's the step people forget until the night before.

The 2025 tags were **not** locked read-only, so existing cards can be rewritten rather
than reordered. Consider pointing the tags at a **redirect you control** so future years
need no reprogramming at all — see
[`next-year-checklist.md`](./next-year-checklist.md).

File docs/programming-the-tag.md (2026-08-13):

# Programming the brother card

The rush link is **not printed on the board.** It lives in the NFC chip's EEPROM,
written after assembly with a phone. That's the good part: the same physical card works
for any year, because you reprogram it instead of reordering it.

**The 2025 tags were not locked read-only**, so every existing brother card can be
rewritten. Only the brother card has a chip — the PNM card is silkscreen only.

## Do this first: point the tags at a redirect you control

**Don't write a destination URL onto the chips. Write a permanent short link that
redirects.**

The 2025 cards were programmed with a URL that has since gone stale — the chapter
website changed and that link is no longer meaningful. The cards themselves are fine;
they just point somewhere that no longer matters. That is a completely avoidable
problem, and it will recur every time the site changes.

Instead, pick a stable path you own — something like `beta.mit.edu/rush` or
`beta.mit.edu/r` — and have it 302-redirect to wherever this year's rush content lives.
Then:

- Cards get programmed **once, ever.** Future years change the redirect target on the
  website and touch no hardware at all.
- A card printed in 2025 keeps working in 2030.
- You can repoint mid-rush if a link breaks, with cards already in people's pockets.
- You get click analytics for free, if the web host offers them.

The chapter has decided to move to this approach. Whoever sets it up should record the
chosen URL here:

```
Permanent redirect URL written to the tags:  <FILL IN ONCE CHOSEN>
Redirect currently points to:                <FILL IN>
```

## What's inside

`U2` is an **NXP NT3H2111W0FHKH** — NTAG I²C *plus*, 1 kB EEPROM, XQFN8 package
(JLCPCB `C710403`). For programming purposes it behaves as a standard **NFC Forum
Type 2 tag**, so any generic NDEF writer works. Its I²C pins are unconnected on this
board; everything happens over RF.

The payload is a single **NDEF URI record**.

Keep the URL short. NDEF URI records use a prefix byte for common schemes
(`https://www.`, `https://`, …), so a short path costs very few bytes — irrelevant
against 1 kB, but short URLs also read faster and are easier to eyeball when verifying a
batch.

## Writing a tag

### Android — the path known to work

Any of these write NDEF to Type 2 tags:

- **NFC TagWriter by NXP** — the vendor app, used for the 2025 cards
- **NFC Tools** (wakdev)
- **NFC TagInfo by NXP** — read-only; use it to *verify*

With TagWriter:

1. *Write tags ▸ New dataset ▸ Link*
2. Enter the URL, choose `https://`
3. *Save & Write*, then hold the card to the back of the phone

**`D1` lighting up means the coil is coupling.** If the LED lights but nothing writes,
the problem is the app or aim, not the antenna.

### iPhone

The 2025 recollection was that iPhone "didn't work," and the most likely reason is
simply that **NFC TagWriter by NXP is Android-only** — it isn't in the App Store, so
there was nothing to try.

iPhones *can* write NDEF tags — iPhone 7 and newer, iOS 13+, via a Core NFC app like
**NFC Tools** (wakdev) or **NFC21 Tools**. Two things trip people up:

- Writing must be driven from inside such an app. iOS's built-in background tag reading
  only *reads*.
- **The iPhone's NFC antenna is at the top edge of the back, not the centre.** Aiming at
  the middle of the phone just fails. This alone explains a lot of "iPhone doesn't work."

**Use an Android phone if you have one** — it's the known-good path and TagWriter gives
clearer errors.

## Don't lock the tags

TagWriter and similar apps offer to make a tag **read-only** by setting the NTAG's lock
bytes. This is **irreversible in hardware**: a locked card can never be rewritten by
anyone, ever.

The 2025 run was left **unlocked**, which is correct and worth continuing. The whole
reusability story — and the redirect strategy above — depends on tags staying writable.
The only argument for locking is stopping a PNM from rewriting a card they were handed,
which isn't a real concern here.

## Verifying a batch

Before handing cards out, check each one with **NFC TagInfo** or NFC Tools:

1. Tap the card
2. Confirm the NDEF record shows the right URL
3. Confirm the tag still reads as writable

Do this per card, not per batch. The realistic failure mode is a single bad joint on one
XQFN8, and a card that reads on the bench is a card that works in someone's hand.

## If cards read at short range

Range depends on how close the antenna's resonance sits to 13.56 MHz.
[`nfc-theory.md`](./nfc-theory.md) covers the measurement in depth — sweeping the antenna
with a network analyzer and adjusting `C2`.

For the 2025 cards `C2` was **2.0 pF** (`0603CG2R0C500NT`), confirmed from the JLCPCB
parts list, and that worked. Upstream's 3.9 pF figure was for *their* board geometry.
Don't change `C2` speculatively — measure first.

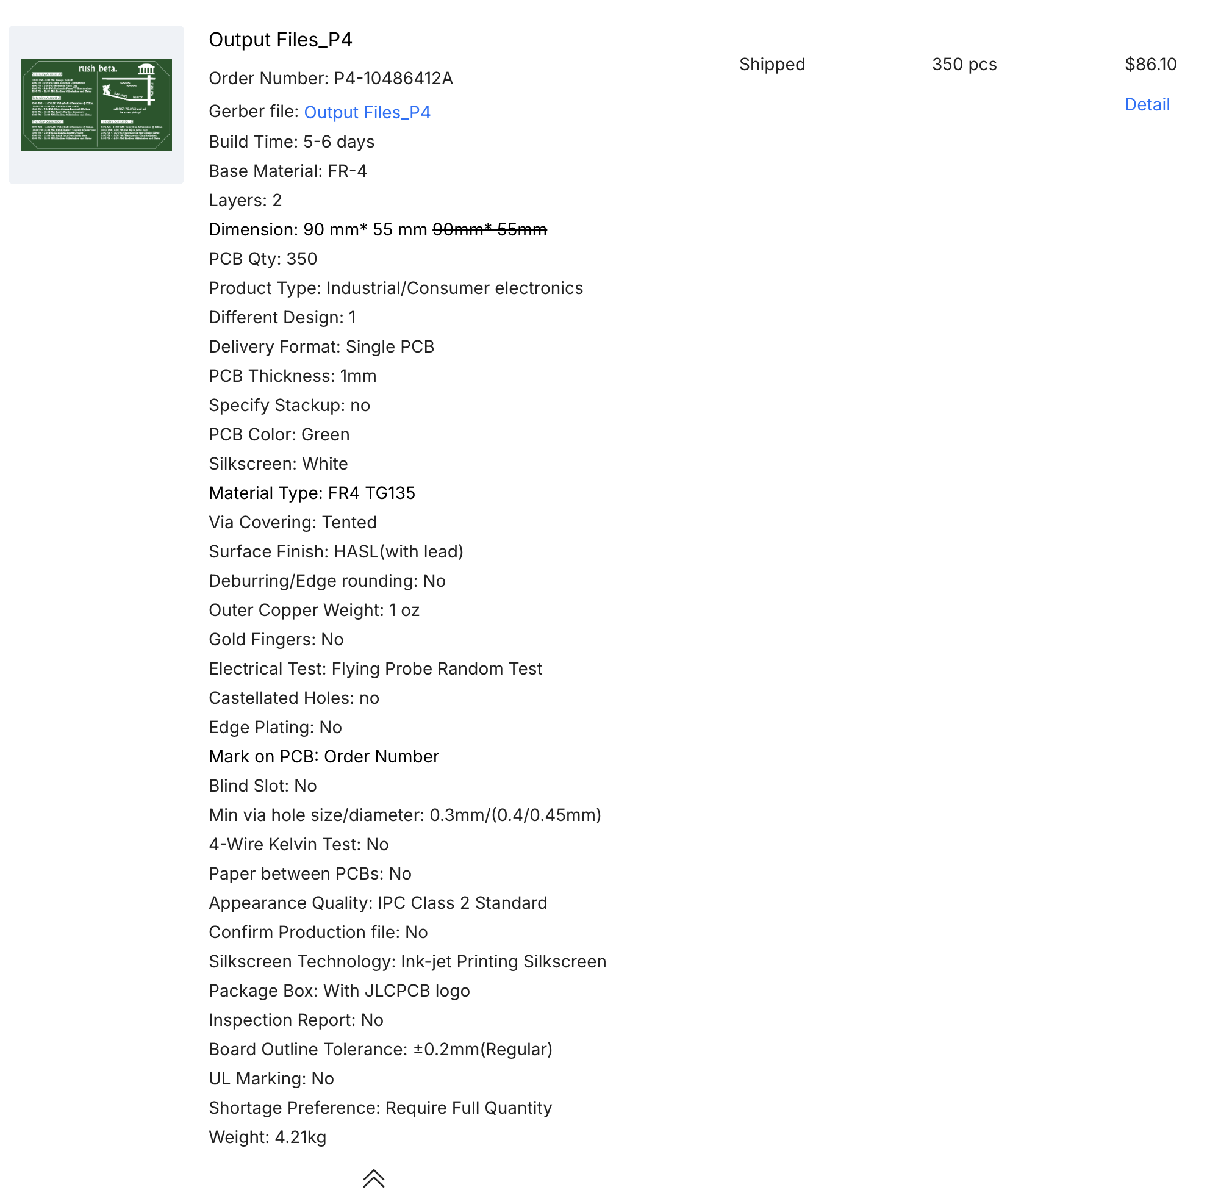
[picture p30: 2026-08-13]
docs/order-history/jlcpcb-p4-pnm-pcb-spec.png

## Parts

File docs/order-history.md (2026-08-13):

# Order history — the 2025 run

Both cards were made by **JLCPCB** under a single order, **`10486412A`**, split into
two products:

| | Product | What | Qty | PCB cost |
|---|---|---|---|---|
| **P3** | `Success_P3` | Brother card, **blue**, **assembled by JLCPCB** | **50** | **$23.70** |
| **P4** | `Output Files_P4` | PNM card, **green**, bare board | **350** | **$86.10** |
| | | | | **≈ $400 paid in total** — see below |

> ### 💸 The real number is **≈ $400 all-in**, not $109.80
>
> The $109.80 above is **only the two PCB line items**. The actual amount paid for the
> whole order was **about $400**, and **delivery and import tariffs took a significant
> chunk of it.**
>
> | | |
> |---|---|
> | PCB line items (documented) | **$109.80** |
> | Assembly + components + shipping + tariffs | **≈ $290** |
> | **Total paid** | **≈ $400** |
>
> The split within that $290 is not recorded — only that shipping and tariffs were a
> large share of it. **Plan against $400, not $110.** The price JLCPCB quotes you on the
> order page is roughly a quarter of what leaves your account, because assembly, parts,
> freight, and US import duty on Chinese-manufactured goods all land afterward.
>
> Blended, that's **~$1 per card across 400 cards** — still cheap for what these are. But
> the 50 brother cards carry essentially all of the assembly and component cost, so their
> true unit cost is many times the PNM cards'.

Reconstructed from `docs/order-history/`: four screenshots of JLCPCB's order pages,
and JLCPCB's own internal CAM job records (`4te.json`) recovered from the production
file downloads.

## Timeline

| Date (2025) | Event |
|---|---|
| **Jul 30** | Gerbers plotted from KiCad 9.0.2 → `fab/2025-07-30_release/` in both cards |
| **Aug 6** | Order `10486412A` placed (JLCPCB accounting timestamp 16:15 UTC) |
| **Aug 9** | P3 brother cards finished — **3 days**, including assembly |
| **Aug 11** | P4 PNM cards finished — **5 days** |
| **Aug 30** | Rush week begins |

**Order to rush: 24 days.** Fabrication itself was only 3–5 days; the rest was
shipping, tag programming, and slack. If you're planning a reorder, three weeks is
comfortable and two is tight but feasible.

## Provenance: the repo's gerbers are exactly what JLCPCB received

Verified by byte-comparison against the gerber sets recovered from the order
downloads:

```
brother-card/fab/2025-07-30_release/  ==  JLCPCB's Success_P3 upload    (byte-identical)
pnm-card/fab/2025-07-30_release/      ==  JLCPCB's Output Files_P4 upload (byte-identical)
```

So reordering from those folders reproduces the 2025 cards exactly. This is not an
inference — the files were diffed.

## As-ordered specification

Both cards shared most settings. **Where the order differs from the KiCad file, the
order wins** — those rows are called out.

| Setting | Brother card (P3) | PNM card (P4) |
|---|---|---|
| Layers | 2 | 2 |
| Base material | FR-4 | FR-4, TG135 |
| **Thickness** | **1 mm** ⚠️ | **1 mm** ⚠️ |
| **Solder mask** | **Blue** ⚠️ | **Green** |
| Silkscreen | White | White |
| Silkscreen process | Ink-jet | Ink-jet |
| Outer copper | 1 oz | 1 oz |
| Surface finish | Lead-free HASL (see note) | HASL with lead |
| Via covering | Tented | Tented |
| Dimension as entered | 88.9 × 70.8 mm (**includes rails**) | 90 × 55 mm |
| Panel | 1 × 1, "single piece, please repeat the data" | Single PCB |
| Electrical test | Flying probe, random | Flying probe, random |
| Appearance | IPC Class 2 | IPC Class 2 |
| Outline tolerance | ±0.2 mm | ±0.2 mm |
| Mark on PCB | Order number | Order number |
| Build time quoted | 3–4 days | 5–6 days |

### ⚠️ 1 mm, not the 1.6 mm in the KiCad file

**Both cards were ordered at 1 mm thickness. Every KiCad file in this repo says
1.6 mm.** Nothing reconciles this automatically — thickness is an order-page dropdown
and is not carried in the gerbers.

1 mm is the right call for something people put in a wallet; 1.6 mm feels like a
circuit board rather than a card. **If you reorder and accept the default, you will
get noticeably chunkier cards than the 2025 run.** Set 1 mm explicitly.

### ⚠️ The brother card is blue, the PNM card is green

The renders in this repo were regenerated to match
([`../tools/render-boards.sh`](../tools/render-boards.sh) injects the as-ordered mask
colour, since KiCad doesn't store it). Upstream's card was green, and the docs
originally assumed the Beta cards were too — they aren't.

Remember the olive/lighter shade on each card is **bare copper under one mask
colour**, not a second mask. On the blue card the copper half reads blue-violet.

### Surface finish: the records disagree

The order page for P3 says **HASL with lead**; JLCPCB's internal CAM record for the
same product says **无铅喷锡 — lead-free HASL**. JLCPCB requires lead-free finish for
assembled boards, which is the likely explanation: the finish was changed when the
product went through SMT. P4 (bare board, no assembly) says leaded in both places.
Not worth chasing, but don't be surprised if a reorder quotes differently once
assembly is added.

## Assembly (brother card only)

**The brother cards were machine-assembled by JLCPCB.** They were not hand-soldered —
which retires the biggest worry about the XQFN8 package.

| Parameter | Value |
|---|---|
| PCBA type | Standard, **top side only** |
| Quantity | 50 |
| Solder paste | High temp |
| Edge rails / fiducials | **Added by JLCPCB** |
| Depanel before delivery | **No** — see below |
| Packaging | Antistatic bubble film |
| Board cleaning / conformal coating / function test | No |
| Photo confirmation | No |
| Assembly build time | 2–3 days |

### The 20 mm of edge rails, and why the dimension says 70.8 mm

The brother card is 88.9 × 50.8 mm, but the order reads 88.9 × **70.8** mm. That's not
a typo. JLCPCB's CAM record spells it out (translated from the Chinese order remark):

> *[System auto-appended: this order is SMT-assembled at JLCPCB. Please check the
> process edge and Mark point requirements; if absent, please add.] Due to SMT process
> requirements the size is now auto-padded to 7 cm — two 1.00 cm process edges must be
> added in the 5.08 cm direction. 【An SMT-specific QR code and human-readable code must
> be added on the process edge, 10 mm from the Mark point, parallel to the board edge,
> added on both sides. Note: this is the SMT-specific QR code.】*

So: 50.8 mm + 2 × 10 mm rails = 70.8 mm. The rails carry the fiducials and JLCPCB's
SMT tracking QR code, and they are **V-scored** off the card — `jlcpcb-cam-p3/vcut.gbr`
in this repo is JLCPCB's V-cut layer, and `qrt.gbr` / `qrb.gbr` are the QR codes.

**Two practical consequences:**

1. **"Depanel boards & edge rail before delivery: No"** — the 50 brother cards arrived
   with the rails still attached. Somebody had to snap 50 rails off along the V-score
   and live with the resulting edge. Combined with "Deburring/Edge rounding: No", those
   two long edges will not be as clean as the routed sides. **For a reorder, paying
   JLCPCB to depanel is worth it on a card you hand to strangers.**
2. The QR code and tracking marks land **on the rails**, so they're discarded with them
   and the card faces stay clean. Good outcome, and worth preserving — if you change the
   panel, check where the marks end up.

Note the PNM card has **no** `vcut` layer and no drill file in its production set,
confirming its octagonal outline was **routed**, as intended.

### Order-number marking

Both products were ordered with **Mark on PCB: Order Number**, meaning JLCPCB prints a
small order number somewhere on the board — JLCPCB chooses where. On the brother card
this was folded into the SMT marks on the rails. **On the PNM card there is likely a
small JLCPCB order number printed on a face**, since it has no rails to hide it on.

If a clean face matters for the PNM card, choose **"Remove order number"** (a small
surcharge) or **"Specify a location"** on the next order.

## The real bill of materials

JLCPCB's parts list from the assembly order — actual manufacturer part numbers and
JLCPCB catalogue codes. This is the authoritative BOM; it supersedes the generic
values in the schematic.

| Ref | Value | Manufacturer part | JLCPCB code | Library tier |
|---|---|---|---|---|
| `U2` | NTAG I²C plus | **NT3H2111W0FHKH** | `C710403` | Extended |
| `C1` | 220 nF 0603 | **CL10B224KA8NNNC** (Samsung, X7R) | `C21120` | **Basic** |
| `C2` | **2.0 pF** 0603 C0G 50 V | **0603CG2R0C500NT** | `C1650` | Extended |
| `R1` | **64.9 Ω** 1% 0603 | **0603WAF649JT5E** (Uniroyal) | `C23224` | Extended |
| `D1` | Red LED 0603 | **LTST-C190KRKT** (Lite-On) | `C94869` | Extended |

Four of the five are **Extended** parts, which at JLCPCB means a per-part feeder setup
fee on top of component cost. That's a fixed cost, so it hurts far less at larger
quantities — relevant if you're deciding between 50 and 200 cards.

### This settles the `C2` question

The tuning capacitor was **2.0 pF** (`0603CG2R0C500NT` — `2R0` = 2.0 pF, C0G, 50 V),
matching the `2p` in the schematic. Upstream's 3.9 pF and 1.5 pF figures were *their*
board, not this one. The Beta cards shipped with 2.0 pF and worked.

If you want to squeeze out more read range you could still sweep the value on hardware
(see [`nfc-theory.md`](./nfc-theory.md)), but **2.0 pF is now a known-good answer, not
a guess** — reorder with it.

## Files to re-upload for a reorder

| Upload this | For |
|---|---|
| `brother-card/fab/2025-07-30_release/` (zipped) | Brother card gerbers |
| `brother-card/fab/jlcpcb-assembly/jlcpcb-bom.csv` | JLCPCB-format BOM |
| `brother-card/fab/jlcpcb-assembly/jlcpcb-cpl.csv` | JLCPCB-format placement (CPL) |
| `pnm-card/fab/2025-07-30_release/` (zipped) | PNM card gerbers |

The BOM and CPL are in JLCPCB's expected column format and are ready to upload as-is.
The BOM's `JLCPCB Part #` column is blank — that's fine, JLCPCB matched the parts from
the manufacturer part numbers, but you can paste the `C…` codes from the table above to
remove any ambiguity.

Then set: **1 mm thickness**, **blue** (brother) / **green** (PNM), white silkscreen,
1 oz copper, tented vias, and **depaneling if you're ordering assembly.**

## What's archived here

```
docs/order-history/
├── jlcpcb-p3-brother-pcb-spec.png    order page: brother card, 50 pcs, $23.70, blue
├── jlcpcb-p4-pnm-pcb-spec.png        order page: PNM card, 350 pcs, $86.10, green
├── jlcpcb-p3-pcba-parameters.png     assembly options for the brother card
├── jlcpcb-p3-pcba-bom.png            the 5 parts with JLCPCB catalogue codes
├── jlcpcb-p3-cam-record.json         JLCPCB's internal CAM job record (brother)
├── jlcpcb-p4-cam-record.json         JLCPCB's internal CAM job record (PNM)
└── jlcpcb-cam-p3/                    JLCPCB's production layers for the brother panel
    ├── vcut.gbr                      V-score lines separating card from edge rails
    ├── qrt.gbr, qrb.gbr              SMT tracking QR codes (on the rails)
    ├── ko.gbr                        board outline as JLCPCB resolved it
    ├── drl.gbr                       drill
    └── ts.gbr, bs.gbr                solder mask
```

The two `*-cam-record.json` files contain **GBK-encoded Chinese strings** — they will
look like mojibake in a UTF-8 editor. To read them:

```sh
python3 -c "
import json,sys
d=json.loads(open(sys.argv[1],'rb').read().decode('utf-8','surrogateescape'))
fix=lambda v: v.encode('utf-8','surrogateescape').decode('gbk') if isinstance(v,str) else v
print(fix(d['orderRemark']))
" docs/order-history/jlcpcb-p3-cam-record.json
```

JLCPCB's bulkier CAM outputs (`.ddw`, `.tgz`, and its re-derived copper/silkscreen
gerbers, ~16 MB) were **not** kept: they're JLCPCB's regeneration of gerbers this repo
already holds byte-identically, so they add weight without adding information.

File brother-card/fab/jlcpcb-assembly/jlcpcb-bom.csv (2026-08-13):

Comment | Designator | Footprint | JLCPCB Part #（optional）
NT3H2111W0FHKH | U2 | nfc-chip
2p | C2 | C_0603_1608Metric
220n | C1 | C_0603_1608Metric
65 | R1 | R_0603_1608Metric
RED | D1 | LED_0603_1608Metric

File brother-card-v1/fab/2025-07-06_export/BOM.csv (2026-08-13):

Id | Designator | Footprint | Quantity | Designation | Supplier and ref
1 | C1 | C_0603_1608Metric | 1 | 220n
2 |  |  | 1
3 | U1 | TSSOP-8_3x3mm_P0.65mm | 1 | NT3H1101W0FTTJ
4 | REF** | COIL_GENERATOR | 1 | COIL_GENERATOR
5 | C2 | C_0603_1608Metric | 1 | 2p
6 | R1 | R_0603_1608Metric | 1 | 65
7 | D1 | LED_0603_1608Metric | 1 | RED

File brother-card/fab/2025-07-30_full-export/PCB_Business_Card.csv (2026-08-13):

Reference | Value | Datasheet | Footprint | Qty | DNP
C1 | 220n | ~ | Capacitor_SMD:C_0603_1608Metric | 1
C2 | 2p | ~ | Capacitor_SMD:C_0603_1608Metric | 1
D1 | RED | ~ | LED_SMD:LED_0603_1608Metric | 1
R1 | 65 | ~ | Resistor_SMD:R_0603_1608Metric | 1
U1 | NT3H1101W0FTTJ | NT3H1101W0FTTJ | Package_SO:TSSOP-8_3x3mm_P0.65mm | 1

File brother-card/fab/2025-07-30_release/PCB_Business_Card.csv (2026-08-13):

Id | Designator | Footprint | Quantity | Designation | Supplier and ref
1 | U2 | nfc-chip | 1 | NT3H2111W0FHKH
2 | C2 | C_0603_1608Metric | 1 | 2p
3 | C1 | C_0603_1608Metric | 1 | 220n
4 |  |  | 1
5 | R1 | R_0603_1608Metric | 1 | 65
6 | D1 | LED_0603_1608Metric | 1 | RED
7 | ANT1 | COIL_GENERATOR | 1 | COIL_GENERATOR

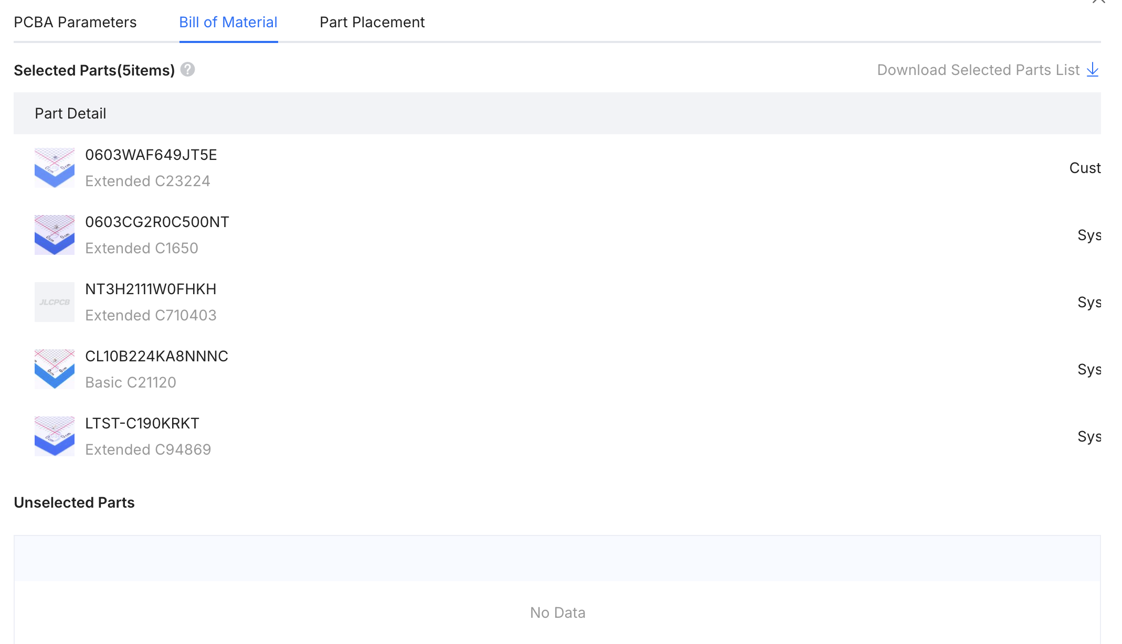
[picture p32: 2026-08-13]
docs/order-history/jlcpcb-p3-pcba-bom.png

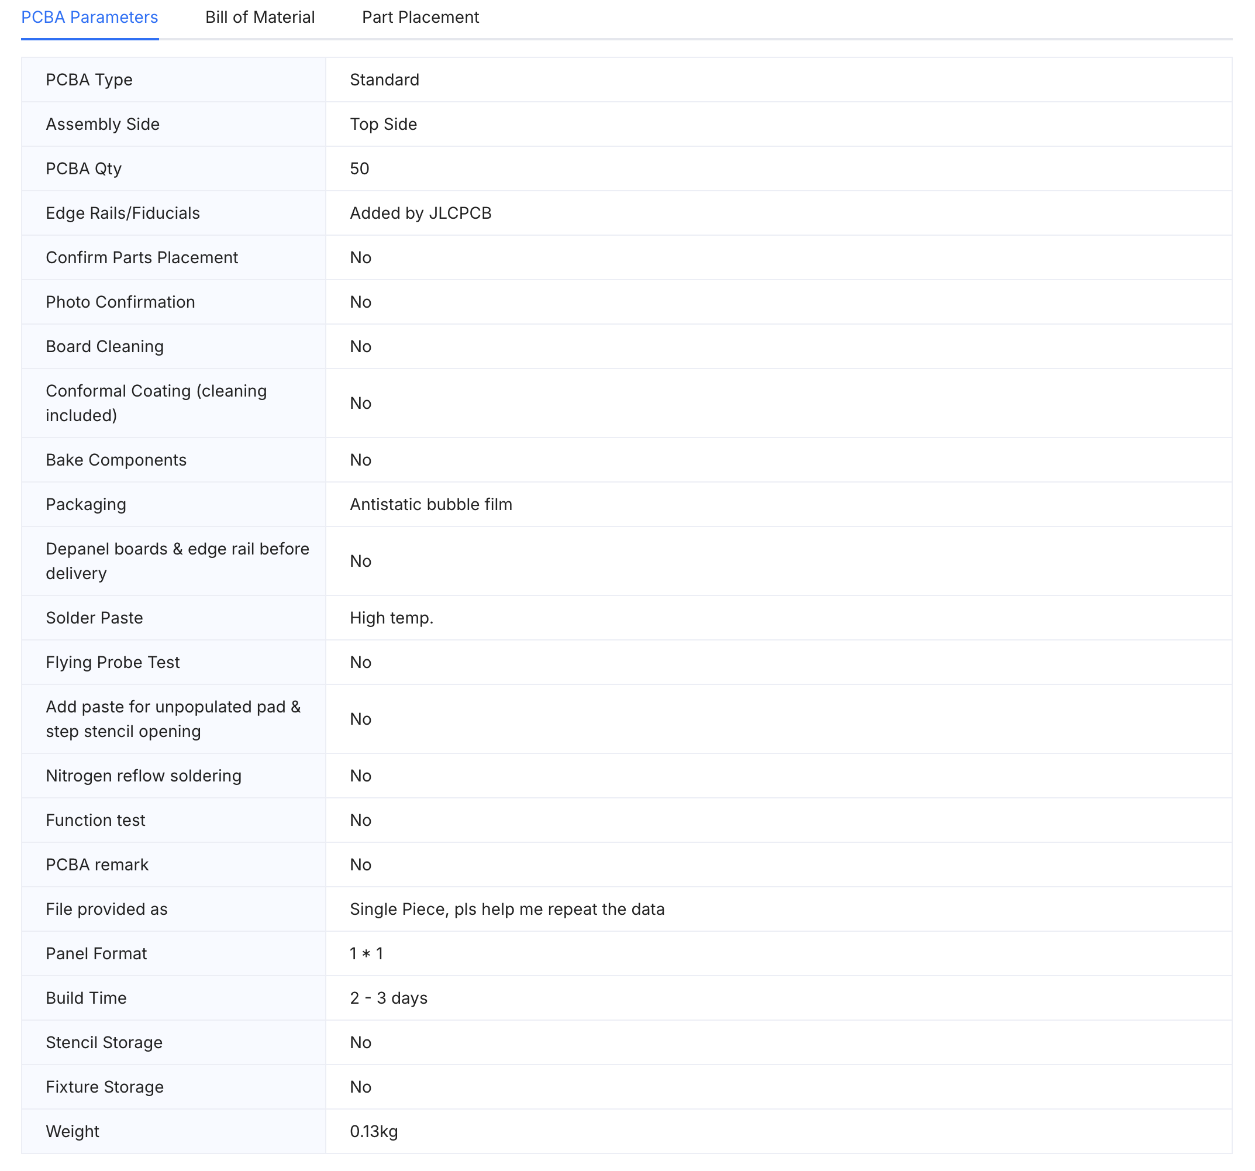
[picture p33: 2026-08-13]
docs/order-history/jlcpcb-p3-pcba-parameters.png

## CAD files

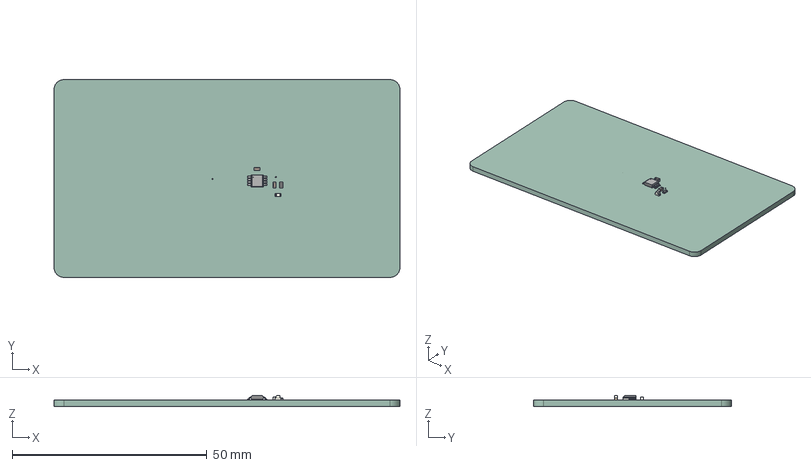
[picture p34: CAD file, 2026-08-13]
docs/renders/upstream-blender/PCB_Business_Card_STEP.step
88.9 x 50.8 x 2.75 mm
C_0603_1608Metric x 2
R_0603_1608Metric
LED_0603_1608Metric
PCB_Business_Card_PCB

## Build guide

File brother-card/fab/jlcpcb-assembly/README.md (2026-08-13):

# JLCPCB assembly inputs

The two files JLCPCB needs to populate the brother card, in its expected column
format. Upload them alongside the gerbers in
[`../2025-07-30_release/`](../2025-07-30_release/) when ordering **PCBA**.

| File | JLCPCB calls it | Contents |
|---|---|---|
| `jlcpcb-bom.csv` | BOM | `Comment, Designator, Footprint, JLCPCB Part #` — the 5 placed parts |
| `jlcpcb-cpl.csv` | CPL / Pick-and-place | `Designator, Mid X, Mid Y, Layer, Rotation` |

These are the files used for the 2025 run (order `10486412A`, product P3, 50 units).

## Notes

**Only 5 parts are listed, and that's correct.** `ANT1` (the spiral antenna) is copper
on the board, not a component, so it must not appear in either file. Neither should the
unnamed single-pad footprint that anchors the coil crossover. If you regenerate these
from KiCad, delete those rows — leaving them in makes JLCPCB's parts matcher fail.

**The `JLCPCB Part #` column is empty.** JLCPCB matched the parts from the manufacturer
part numbers in the `Comment` field for the 2025 order, so blank worked. To remove any
ambiguity, paste in the catalogue codes:

| Designator | Comment as submitted | Actual part ordered | JLCPCB code |
|---|---|---|---|
| `U2` | `NT3H2111W0FHKH` | NT3H2111W0FHKH | `C710403` |
| `C1` | `220n` | CL10B224KA8NNNC | `C21120` |
| `C2` | `2p` | 0603CG2R0C500NT (2.0 pF C0G 50 V) | `C1650` |
| `R1` | `65` | 0603WAF649JT5E (64.9 Ω 1%) | `C23224` |
| `D1` | `RED` | LTST-C190KRKT | `C94869` |

Note how loose the `Comment` values were — `65`, `2p`, `RED` — and JLCPCB still resolved
them sensibly. Filling in the codes makes the order deterministic instead of relying on
that.

**Coordinates are absolute KiCad board coordinates with negative Y**, exactly as KiCad
exports them. JLCPCB accepts this; don't "fix" the signs.

Full context, including the edge rails JLCPCB adds for assembly and why depaneling is
worth paying for, is in [`../../../docs/order-history.md`](../../../docs/order-history.md).

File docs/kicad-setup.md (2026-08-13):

# Opening these projects, years later

## The short version

```sh
git clone <this repo>
cd RushCards
```

Then in KiCad: **File ▸ Open Project** → `brother-card/PCB_Business_Card.kicad_pro`
(or `pnm-card/PNM_Rush_Card.kicad_pro`).

That's it. There is no build step, no dependency to install, and no environment
variable to set. If footprints are missing, something moved — read on.

## What these were built with

| | |
|---|---|
| KiCad | **9.0.2** (both cards, all fab exports) |
| OS at design time | macOS |
| Stock libraries | KiCad's bundled `Capacitor_SMD`, `Resistor_SMD`, `LED_SMD`, `Device`, `Connector` |
| Custom library | `lib/` in this repo — see [`../lib/README.md`](../lib/README.md) |

## Opening in a newer KiCad

KiCad will offer to migrate the file format on first open. **Let it, but do it on a
branch**, because a migration rewrites every source file and produces an enormous
diff that buries any real change you make afterward.

```sh
git switch -c kicad-10-migration
# open, let KiCad migrate, save, then:
git add -A && git commit -m "Migrate brother-card + pnm-card to KiCad 10 format"
```

Two things behave differently after a migration:

1. **Regenerated gerbers will not be byte-identical to `fab/`.** This was measured,
   not guessed: replotting the brother card in KiCad 10.0.5 produced different zone
   fill and teardrop geometry from the KiCad 9.0.2 release set. Neither is "wrong",
   but this artwork leans on copper zone fills, so the archived gerbers are the
   record of what physically exists. See [`reordering.md`](./reordering.md).
2. **DRC results shift between versions.** The counts documented in each card's
   README were measured with KiCad 10.0.5. Expect different numbers on a different
   version. What matters is that they're all artwork artifacts — each card README
   explains its own list.

## If footprints or symbols come up missing

Almost always one of these three:

**1. `lib/` moved.** Projects resolve it as `${KIPRJMOD}/../lib/btp.pretty` — a
relative hop from the project folder up one level into `lib/`. If you copied
`brother-card/` somewhere on its own, that hop breaks. Copy the whole repo, or fix
the project's `fp-lib-table`.

**2. You have a conflicting *global* `btp` library.** Anyone who worked on the
original machine has `btp` registered globally at
`~/Documents/KiCad/9.0/footprints/btp.pretty`. Two libraries sharing one nickname is
a conflict. Delete the global entry in
*Preferences ▸ Manage Footprint Libraries ▸ Global* so the project-local one wins.

**3. It's one of the known stale links, and it's fine.** These are expected and do
not need fixing:

| Where | Stale reference | Status |
|---|---|---|
| brother v2, PNM | footprint `LOGO` (no library prefix) | Geometry is stored in the `.kicad_pcb` and fabricates correctly. Twin available as `btp:btp-text-only-lg`. |
| brother v2 | an unnamed single-pad footprint | The coil crossover anchor. Stored in the board. Don't delete. |
| brother **v1** | symbol lib `NT3H1101W0FTTJ`, footprint `COIL_GENERATOR` (no prefix) | Pointed at `C:/Users/rahim/Downloads/...` on upstream's Windows machine. Symbol definitions are cached in the `.kicad_sch`, so it opens; you just can't update from library. v1 was never fabricated. |

KiCad caches complete symbol and footprint definitions inside `.kicad_sch` and
`.kicad_pcb`. A missing *library* does not mean missing *geometry* — it only means
you can't push or pull updates for that part.

## What's deliberately not in git

Per [`../.gitignore`](../.gitignore):

- `fp-info-cache` — multi-MB, regenerated on open
- `*.kicad_prl` — per-user GUI state (zoom, visible layers, open tabs); pure diff noise
- `*-backups/` — KiCad's own timestamped project zips. **These still exist on the
  original machine's disk** (~16 MB across the three projects); they're just kept out
  of git, since git history covers the same ground. They contain snapshots from
  2024-03 through 2025-07 including one discarded 2025-07-31 autosave.

## Regenerating the renders

Run the script — don't hand-roll the commands:

```sh
tools/render-boards.sh
```

It rewrites everything in `renders/` in about 90 seconds.

**Why a script rather than a one-liner:** the cards were manufactured in specific mask
colours (brother card **blue**, PNM card **green**) and KiCad stores no mask colour at
all, so a naive render comes out the default green and misrepresents the brother card.
The script copies each project to a temp directory, injects a `(color …)` field into the
copy's stackup, and renders with `--use-board-stackup-colors`. **The board files
themselves are never modified** — they're the as-fabricated record.

If you do want a quick one-off in default colours:

```sh
export PATH="/Applications/KiCad/KiCad.app/Contents/MacOS:$PATH"
kicad-cli pcb render --side top --width 2400 --height 1400 --quality high \
  -o /tmp/front.png brother-card/PCB_Business_Card.kicad_pcb
```

`kicad-cli` is also how the DRC numbers in each README were measured:

```sh
kicad-cli pcb drc --format json -o /tmp/drc.json brother-card/PCB_Business_Card.kicad_pcb
```

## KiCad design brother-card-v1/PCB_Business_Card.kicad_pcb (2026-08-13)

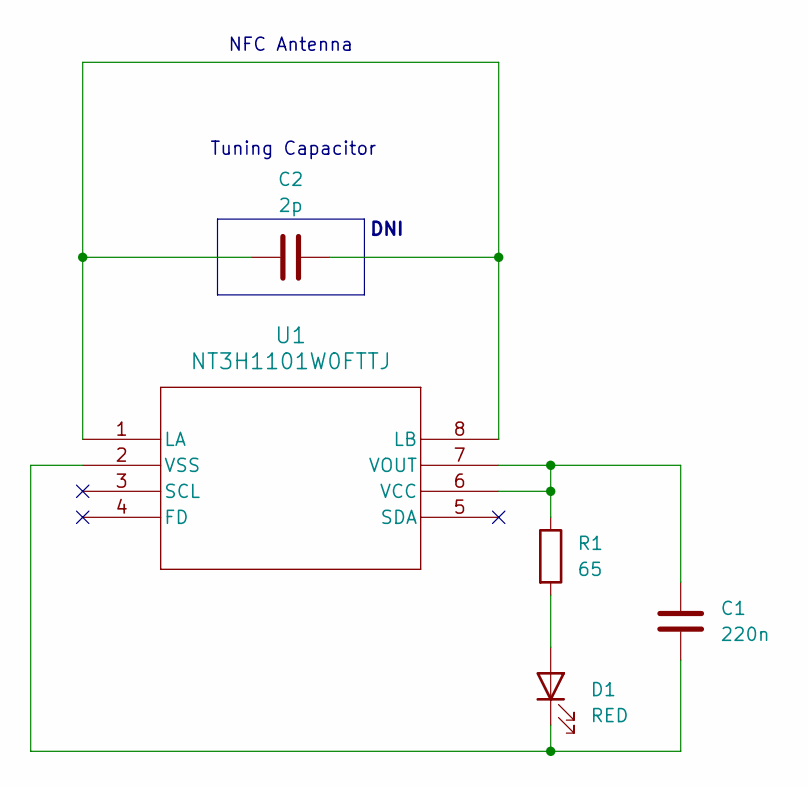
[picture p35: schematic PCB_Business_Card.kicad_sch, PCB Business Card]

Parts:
C1: 220n; C_0603_1608Metric
C2: 2p; C_0603_1608Metric
D1: RED; LED_0603_1608Metric
R1: 65; R_0603_1608Metric
U1: NT3H1101W0FTTJ; TSSOP-8_3x3mm_P0.65mm

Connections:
unnamed: D1.2 (A), R1.2
unnamed: C1.2, D1.1 (K), U1.2 (VSS)
unnamed: C2.1, C2.2, U1.1 (LA), U1.8 (LB)
unnamed: C1.1, R1.1, U1.6 (VCC), U1.7 (VOUT)

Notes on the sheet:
DNI
NFC Antenna
Tuning Capacitor

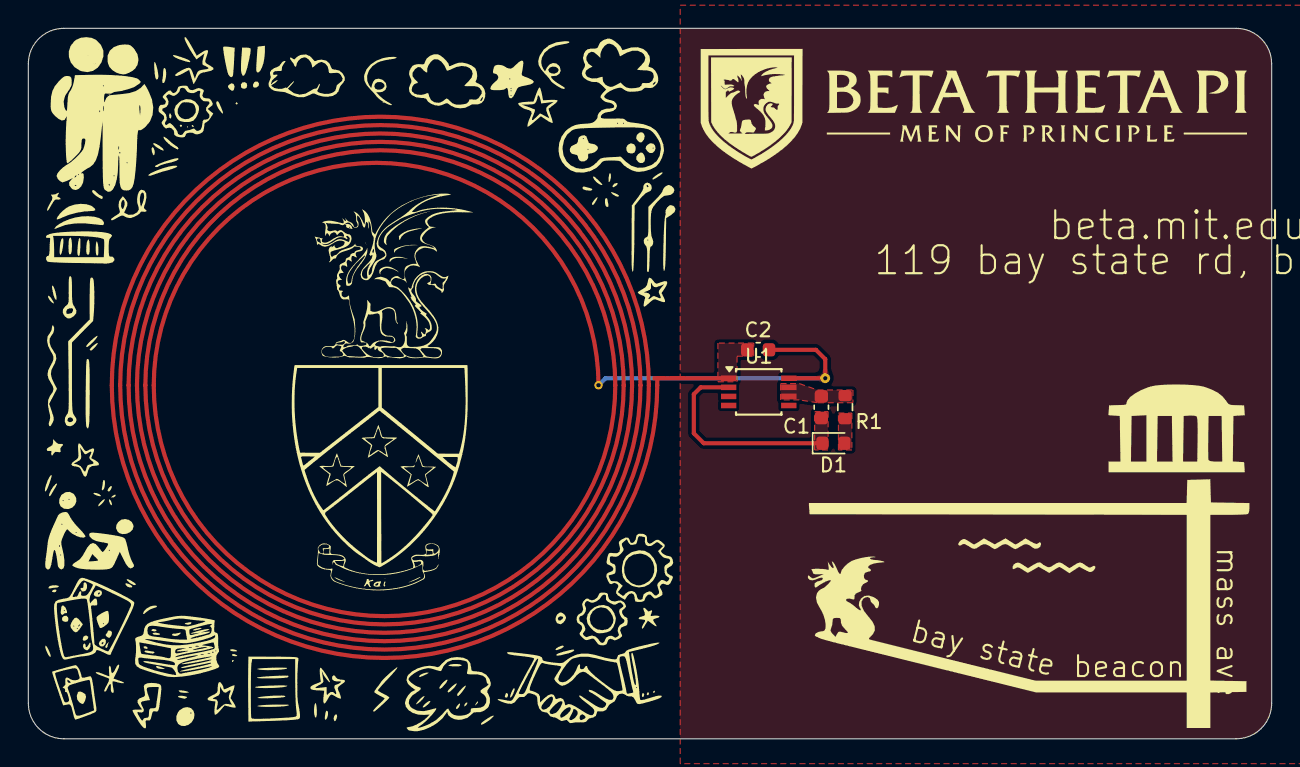
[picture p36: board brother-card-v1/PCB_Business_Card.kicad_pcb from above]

Board: 2 copper layers, 88.9 x 50.8 mm, 5 parts (0 on the bottom side), 4 nets.

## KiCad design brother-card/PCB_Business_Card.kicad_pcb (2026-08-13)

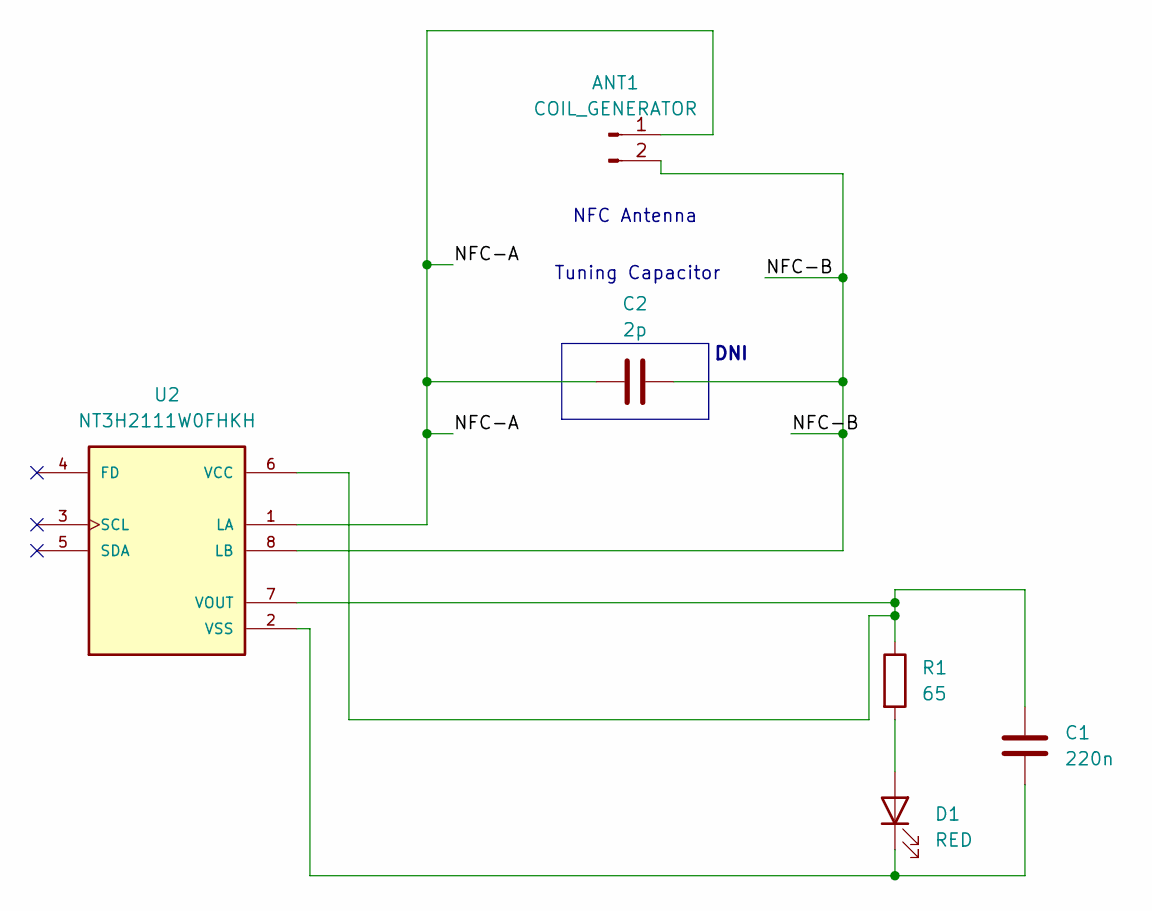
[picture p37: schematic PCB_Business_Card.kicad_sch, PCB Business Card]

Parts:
ANT1: COIL_GENERATOR
C1: 220n; C_0603_1608Metric
C2: 2p; C_0603_1608Metric
D1: RED; LED_0603_1608Metric
R1: 65; R_0603_1608Metric
U2: NT3H2111W0FHKH; nfc-chip

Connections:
/NFC-A: ANT1.1, C2.1, U2.1 (LA)
/NFC-B: ANT1.2, C2.2, U2.8 (LB)
unnamed: D1.2 (A), R1.2
unnamed: C1.2, D1.1 (K), U2.2 (VSS)
unnamed: C1.1, R1.1, U2.6 (VCC), U2.7 (VOUT)

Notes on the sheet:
DNI
NFC Antenna
Tuning Capacitor

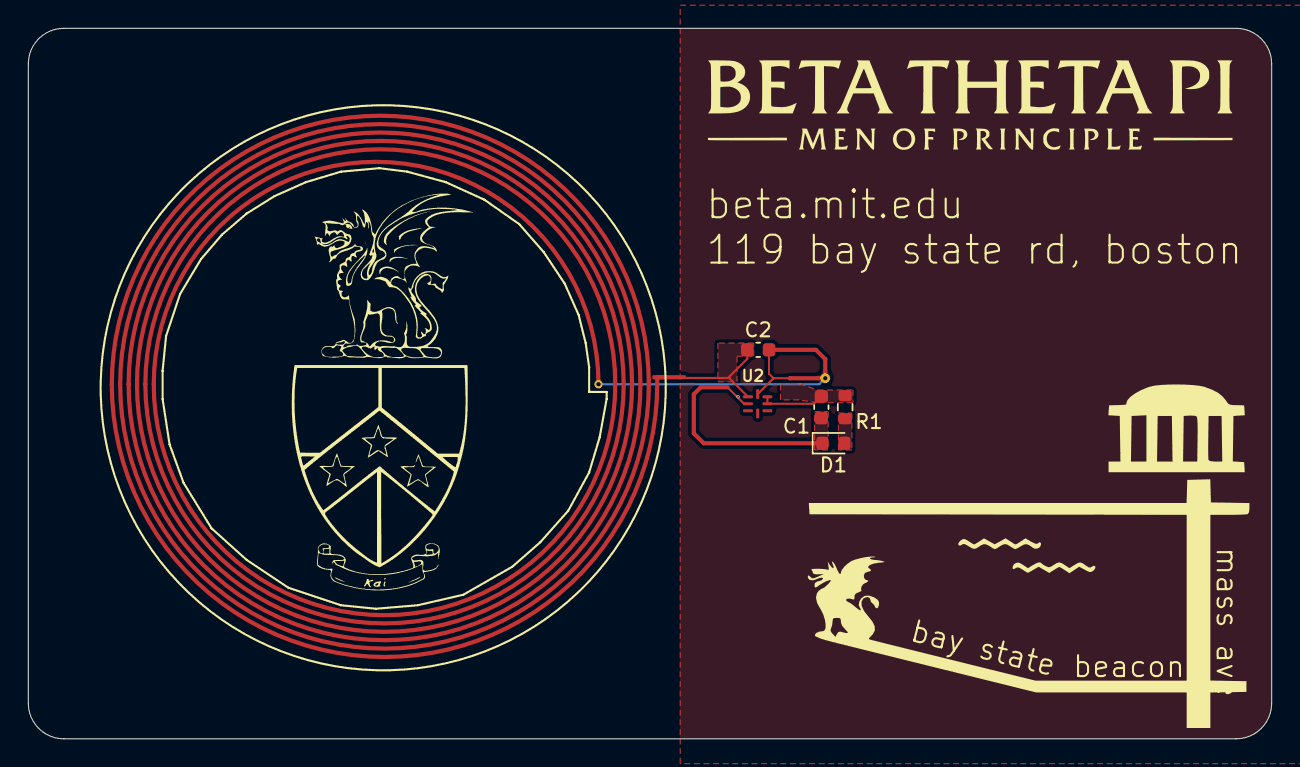
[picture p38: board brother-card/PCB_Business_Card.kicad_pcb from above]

Board: 2 copper layers, 88.9 x 50.8 mm, 6 parts (0 on the bottom side), 5 nets.

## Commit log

2026-08-13 Archive the 2025 Beta Theta Pi rush PCB cards
    Turns a year-old folder of KiCad work into a self-contained, reopenable
    archive of the two cards made for MIT Beta Theta Pi rush week 2025.
    Structure:
    brother-card/ NFC tag card, v2 -- the version that was fabricated
    brother-card-v1/ earlier iteration, never fabricated
    pnm-card/ silkscreen-only rush schedule card
    lib/ vendored btp.pretty + btp.kicad_sym
    docs/ written docs + inherited upstream reference material
    The critical fix: all three boards depended on a `btp` library registered
    in KiCad's *global* table on one laptop, so they were unopenable by anyone
    else. The library is now vendored i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
    [Antenna_Shape_Calculator.xlsx, BOM.csv, Class_4.brd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]
2026-08-13 Add MIT license with an explicit attribution boundary
    MIT covers Beta's original work: the artwork, the btp library, the board
    layouts, the PNM card, and this documentation.
    The NOTICE section names what MIT does NOT cover, so the boundary is
    unambiguous rather than implied:
    - upstream's material (docs/nfc-theory.md, docs/images/,
    docs/antenna-simulations/, docs/renders/upstream-blender/), which is
    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
2026-08-13 Add the 2025 JLCPCB order record; correct thickness, colour, and assembly
    Reconstructs the manufacturing history from salvaged order screenshots and
    JLCPCB's own CAM job records. This closes most of OPEN-QUESTIONS and corrects
    four things the docs previously got wrong or guessed at.
    Vendor was JLCPCB, not PCBWay: order 10486412A, placed 2025-08-06.
    P3 brother card 50 pcs $23.70 blue, assembled by JLCPCB
    P4 PNM card 350 pcs $86.10 green, bare board
    Finished Aug 9 / Aug 11, three weeks before rush. Assembly and component
    cost are NOT in the salvaged records and remain open.
    Corrections:
    - Thickness is 1 mm, not the 1.6 mm every KiCad file states. Thickness is
    an order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
    [jlcpcb-bom.csv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]
2026-08-13 Record the real ~$400 order total; close the photos question as "none exist"
    Cost: the documented PCB line items were $109.80, but about $400 was actually
    paid for the order once assembly, components, delivery, and US import tariffs
    were counted, with freight and tariffs taking a significant share. The split
    among those four isn't recorded and isn't worth chasing.
    The planning takeaway is what matters, and it's now in reordering.md,
    next-year-checklist.md, order-history.md and the top-level README: budget
    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
